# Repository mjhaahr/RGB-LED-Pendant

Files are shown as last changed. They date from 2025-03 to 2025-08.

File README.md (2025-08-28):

# Small RGB LED Pendant with User-Selectable Patterns

Assembled Device

Features:
- 177 Addressable RGB LEDs
    - WS2812B-style (NeoPixel) control
    - Xinglight XL-1010RGBC-WS2812B
- Two-board design for tight packaging
    - Front board contains the LED Matrix
    - Back board holds the Microcontroller, IMU, and Power Regulation
- ESP32-C3 Module for control
    - Allows pattern changing over WiFi/Bluetooth, as well as the buttons on the device
- Onboard IMU to generate reactive patterns
    - Utilizes a Bosch BNO055 for the simplicity of the orientation solution
- USB C Port for Power, Comms, and Programming
    - Connects to the ESP32-C3's onboard USB-CDC/JTAG device

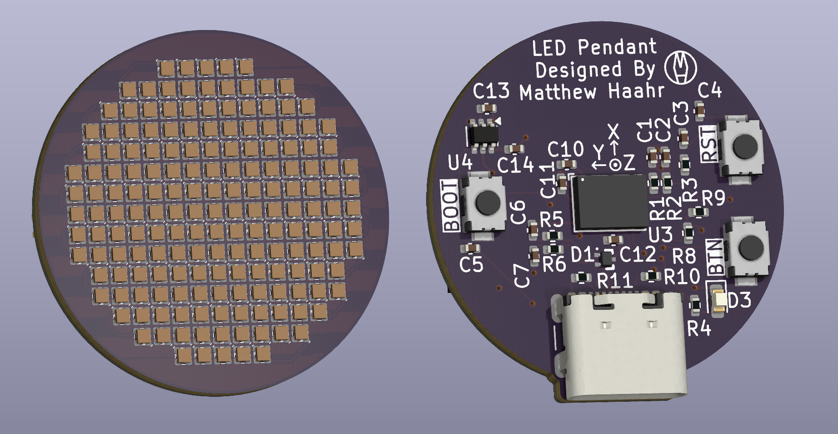
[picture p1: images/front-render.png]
Front Side PCB Render


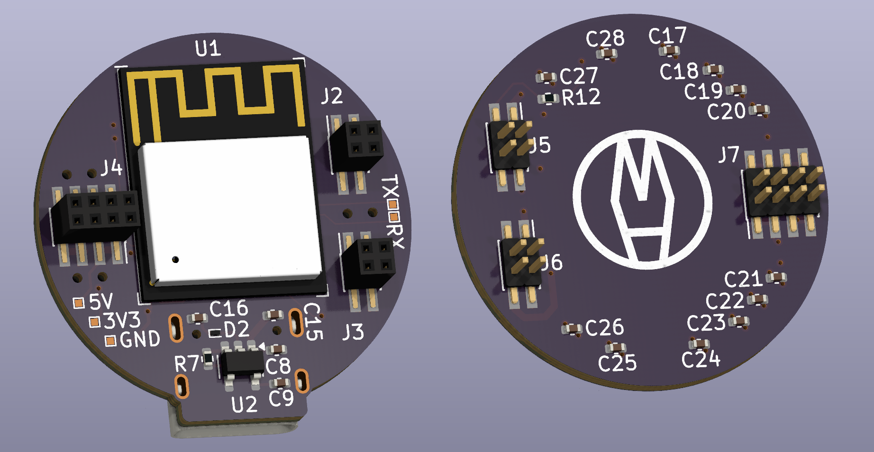
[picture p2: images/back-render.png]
Back Side PCB Render


## Table Of Contents
- [Bill Of Materials](#bill-of-materials)
- [Fabrication and Assembly](#fabrication-and-assembly)
- [Case Design](#case-design)
- [Code](#code)
- [Extra Notes](#extra-notes)

Microcontroller Schematic Page
LED Matrix Schematic Page
LED Support (Capacitors and Connectors) Schematic Page

## Bill of Materials
- 1x Espressif ESP32-C3-MINI-1 - Microcontroller Module w/ WiFi and Bluetooth
    - [Datasheet](https://www.espressif.com/sites/default/files/documentation/esp32-c3-mini-1_datasheet_en.pdf)
    - [LCSC Part Number: C2934569](https://www.lcsc.com/product-detail/WiFi-Modules_Espressif-Systems-ESP32-C3-MINI-1-H4_C2934569.html)
    - Component: U1
- 1x Diodes Incorporated AP2112K-3.3 - Fixed 3V3 Regulator
    - [Datasheet](https://www.diodes.com/assets/Datasheets/AP2112.pdf)
    - [LCSC Part Number: C51118](https://www.lcsc.com/product-detail/Voltage-Regulators-Linear-Low-Drop-Out-LDO-Regulators_Diodes-Incorporated-AP2112K-3-3TRG1_C51118.html)
    - Component: U2
- 1x Bosch Sensortec BNO055 - Absolute Orientation Sensor - 9 Axis IMU and Sensor Fusion Processor
    - [Datasheet](https://www.bosch-sensortec.com/media/boschsensortec/downloads/datasheets/bst-bno055-ds000.pdf)
    - [LCSC Part Number: C93216](https://www.lcsc.com/product-detail/Accelerometers_Bosch-Sensortec-BNO055_C93216.html)
    - Component: U3
- 1x TI SN74LVC1T45DCK - Logic Level Translator
    - [Datasheet](https://www.ti.com/lit/ds/symlink/sn74lvc1t45.pdf)
    - [LCSC Part Number: C9382](https://www.lcsc.com/product-detail/Translators-Level-Shifters_Texas-Instruments-SN74LVC1T45DCKR_C9382.html)
    - Component: U4
- 1x Tech Public TPD2EUSB30 - 2-Channel USB ESD/TVS Diode (Clone of TI part with the same name)
    - [Datasheet](https://www.ti.com/lit/ds/symlink/tpd2eusb30.pdf)
    - [LCSC Part Number: C5182099](https://www.lcsc.com/product-detail/ESD-and-Surge-Protection-TVS-ESD_TECH-PUBLIC-TPD2EUSB30DRTR_C5182099.html)
    - Component: D1
- 1x TI ESD441 - 1-Channel VBUS ESD Diode
    - [Datasheet](https://www.ti.com/lit/ds/symlink/esd441.pdf)
    - [LCSC Part Number: C22427765](https://www.lcsc.com/product-detail/ESD-and-Surge-Protection-TVS-ESD_Texas-Instruments-ESD441DPLR_C22427765.html)
    - Component: D2
- 1x XINGLIGHT XL-1608SYGC-04 - Green LED
    - [Datasheet](https://www.lcsc.com/datasheet/lcsc_datasheet_2410121310_XINGLIGHT-XL-1608SYGC-04_C965806.pdf)
    - [LCSC Part Number: C965806](https://www.lcsc.com/product-detail/LED-Indication-Discrete_XINGLIGHT-XL-1608SYGC-04_C965806.html)
    - Component: D3
- 177x Xinglight XL-1010RGBC-WS2812B - 1mm x 1mm Addressable RGB LED
    - [Datasheet](https://www.lcsc.com/datasheet/lcsc_datasheet_2410121315_XINGLIGHT-XL-1010RGBC-WS2812B_C5349953.pdf)
    - [LCSC Part Number: C5349953](https://www.lcsc.com/product-detail/RGB-LEDs-Built-in-IC_XINGLIGHT-XL-1010RGBC-WS2812B_C5349953.html)
    - Component: D4-D180
- 3x Bossie BX-TS-26-342TP - SMD Tactile Push Buttons:
    - [Datasheet](https://www.lcsc.com/datasheet/lcsc_datasheet_2410121625_Bossie-BX-TS-26-342TP_C18078117.pdf)
    - [LCSC Part Number: C18078117](https://www.lcsc.com/product-detail/Tactile-Switches_Bossie-BX-TS-26-342TP_C18078117.html)
    - Component: SW1-SW3
- 1x G-Switch GT-USB-9010AB - USB 2.0 USB-C Connector (GCT-USB4105-GF Clone)
    - [Datasheet](https://www.lcsc.com/datasheet/lcsc_datasheet_2411221125_G-Switch-GT-USB-9010AB_C2988366.pdf)
    - [LCSC Part Number: C2988366](https://www.lcsc.com/product-detail/USB-Connectors_G-Switch-GT-USB-9010AB_C2988366.html)
    - Component: J1
- Headers (Used as Interboard Connectors)
    - 2x 2x2 Pin Socket - 1.27mm Pitch - Vertical SMD
        - Component: J2, J3
        - [LCSC Part Number: C5160799](https://www.lcsc.com/product-detail/Female-Headers_DEALON-DW127S-22-04-43_C5160799.html)
    - 1x 2x4 Pin Socket - 1.27mm Pitch - Vertical SMD
        - Component: J4
        - [LCSC Part Number: C5160801](https://www.lcsc.com/product-detail/Female-Headers_DEALON-DW127S-22-08-43_C5160801.html)
    - 2x 2x2 Pin Header - 1.27mm Pitch - Vertical SMD
        - Component: J5, J6
        - [LCSC Part Number: C5160758](https://www.lcsc.com/product-detail/Pin-Headers_DEALON-DZ127S-22-04-55_C5160758.html)
    - 1x 2x4 Pin Header - 1.27mm Pitch - Vertical SMD
        - Component: J7
        - [LCSC Part Number: C5160760](https://www.lcsc.com/product-detail/Pin-Headers_DEALON-DZ127S-22-08-55_C5160760.html)
- Capacitors
    - *All Packages are 0402 unless otherwise noted*
    - 10µF
        - Component: C1, C8, C9, C16
        - [LCSC Part Number: C7472949](https://www.lcsc.com/product-detail/Multilayer-Ceramic-Capacitors-MLCC-SMD-SMT_Chinocera-HGC0402R5106M100NTEJ_C7472949.html)
    - 100nF
        - Component: C2, C4, C5, C10, C13, C14, C17-C28
        - [LCSC Part Number: C1525](https://www.lcsc.com/product-detail/Multilayer-Ceramic-Capacitors-MLCC-SMD-SMT_Samsung-Electro-Mechanics-CL05B104KO5NNNC_C1525.html)
    - 1µF
        - Component: C3, C12, C15
        - [LCSC Part Number: C14445](https://www.lcsc.com/product-detail/Multilayer-Ceramic-Capacitors-MLCC-SMD-SMT_Samsung-Electro-Mechanics-CL05A105KP5NNNC_C14445.html)
    - 22pF
        - Component: C6, C7
        - [LCSC Part Number: C106203](https://www.lcsc.com/product-detail/Multilayer-Ceramic-Capacitors-MLCC-SMD-SMT_YAGEO-CC0402JRNPO9BN220_C106203.html)
    - 120nF
        - Component: C11
        - [LCSC Part Number: C7393864](https://www.lcsc.com/product-detail/Multilayer-Ceramic-Capacitors-MLCC-SMD-SMT_CCTC-TCC0402X7R124K160AT_C7393864.html)
- Resistors:
    - *All Packages are 0402 unless otherwise noted*
    - 3.3kΩ
        - Component: R1, R2
        - [LCSC Part Number: C25890](https://www.lcsc.com/product-detail/Chip-Resistor-Surface-Mount_UNI-ROYAL-Uniroyal-Elec-0402WGF3301TCE_C25890.html)
    - 10kΩ
        - Component: R3, R8, R9, R12
        - [LCSC Part Number: C25744](https://www.lcsc.com/product-detail/Chip-Resistor-Surface-Mount_UNI-ROYAL-Uniroyal-Elec-0402WGF1002TCE_C25744.html)
    - 1.3kΩ
        - Component: R4
        - [LCSC Part Number: C25866](https://www.lcsc.com/product-detail/Chip-Resistor-Surface-Mount_UNI-ROYAL-Uniroyal-Elec-0402WGF1301TCE_C25866.html)
    - 0Ω
        - Component: R5, R6
        - [LCSC Part Number: C17168](https://www.lcsc.com/product-detail/Chip-Resistor-Surface-Mount_UNI-ROYAL-Uniroyal-Elec-0402WGF0000TCE_C17168.html)
    - 100kΩ
        - Component: R7
        - [LCSC Part Number: C25741](https://www.lcsc.com/product-detail/Chip-Resistor-Surface-Mount_UNI-ROYAL-Uniroyal-Elec-0402WGF1003TCE_C25741.html)
    - 5.1kΩ
        - Component: R10, R11
        - [LCSC Part Number: C25905](https://www.lcsc.com/product-detail/Chip-Resistor-Surface-Mount_UNI-ROYAL-Uniroyal-Elec-0402WGF5101TCE_C25905.html)
    - 470Ω
        - Component: R13
        - [LCSC Part Number: C25117](https://www.lcsc.com/product-detail/Chip-Resistor-Surface-Mount_UNI-ROYAL-Uniroyal-Elec-0402WGF4700TCE_C25117.html)

## Fabrication and Assembly
- The boards were fabricated and assembled by JLCPCB
- The boards were combined into one frame to reduce the cost of having to make and assemble two designs in one order
- The frame was enlarged to fit the minimum board size for JLCPCB's PCBA service, as well as providing the necessary fiducials and edge rails for assembly

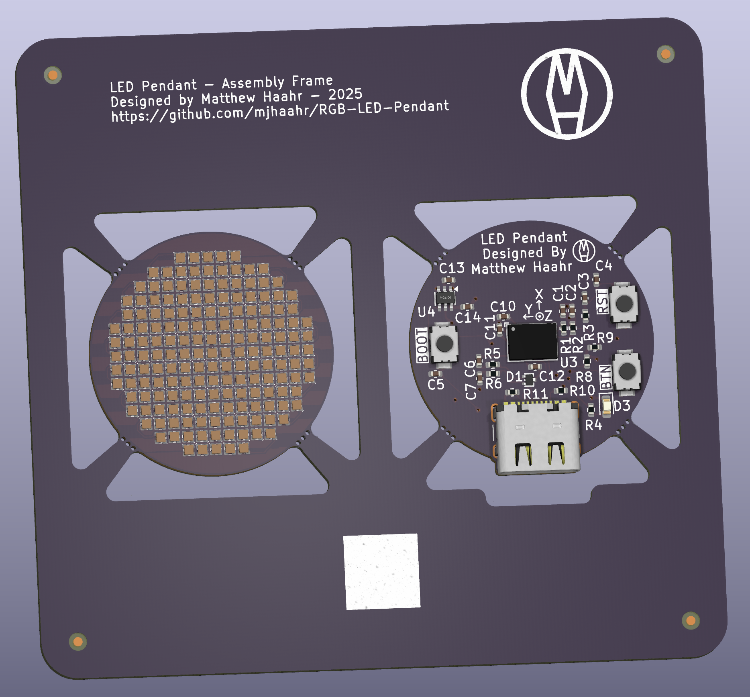
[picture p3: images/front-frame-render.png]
Front Side Assembly Frame Render


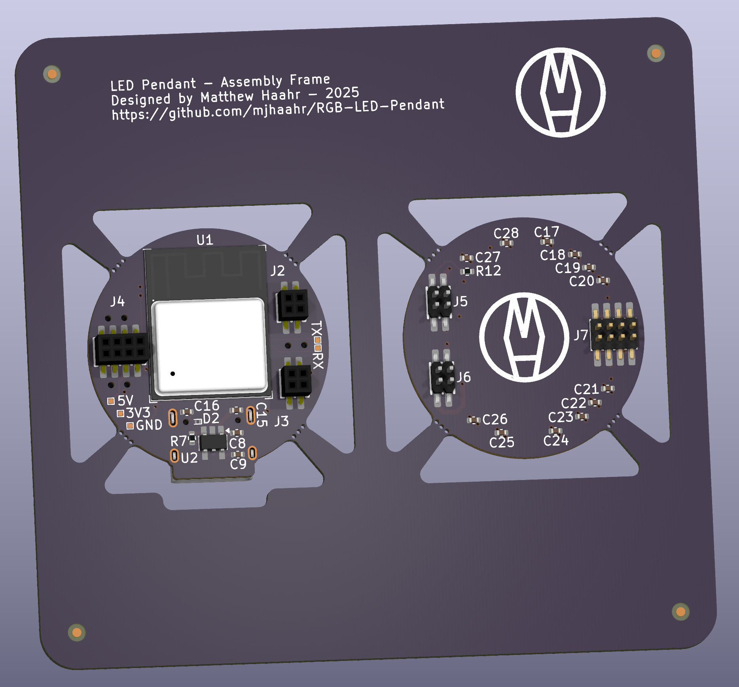
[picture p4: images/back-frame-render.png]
Back Side Assembly Frame Render


## Case Design
<!--- *TODO: Make Alternate with no Loop* --->
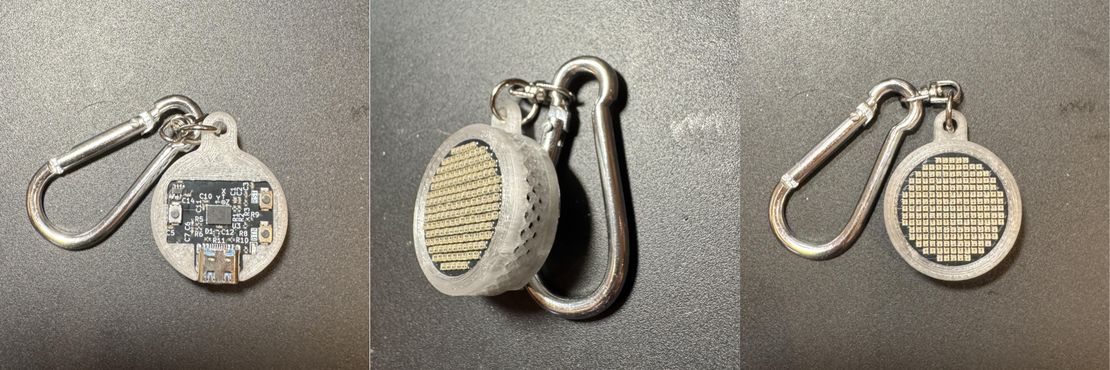
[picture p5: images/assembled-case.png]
Assembled Case


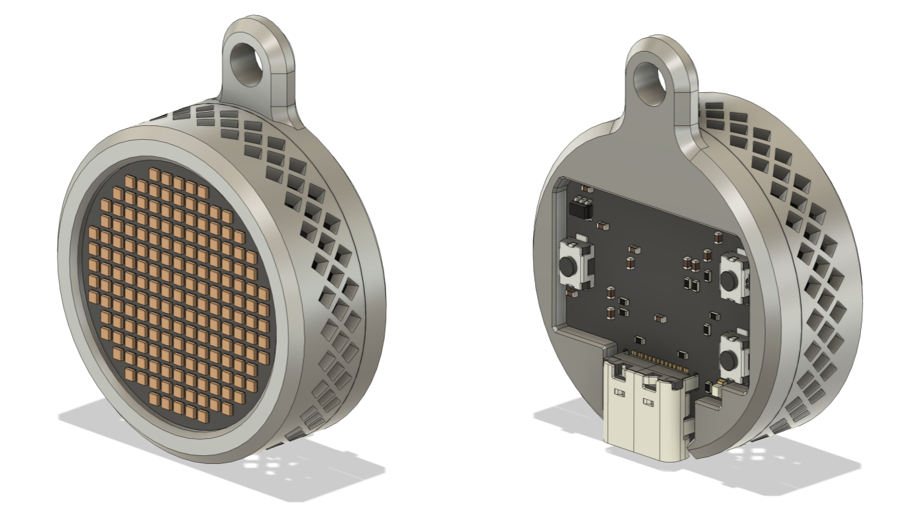
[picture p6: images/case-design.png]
Case Design


- 3D Printed Case with Keyring Loop
- Due to the small size, the two halves must be glued together, so ensure the whole pendant works before gluing together
- Included are the [CAD Files](case/Models) and [STLs](case/3D_Prints)

## Code
- Open the [Arduino Project](code/Small_Pendant) (Small_Pendant.ino and the rest of the directory)
- Ensure the ESP32 Arduino Core is installed and select the ESP32C3 Dev Module
- Plug in the pendant and click upload

## Extra Notes
- The [Only Pendant](https://github.com/mjhaahr/RGB-LED-Pendant/tree/Only_Pendant) branch features a much-simplified design, with only the LED Matrix and no control board; it functions the same as a normal NeoPixel matrix.
- A future version may replace the BNO055 with a more up-to-date IMU (and one that is a still active product) and move the orientation calculation onto the main MCU
- A future design may include an onboard battery and charger (would likely require enlarging the board or adding thickness to the design)
- During standup of V1 Hardware, it was found that an MCU strapping pin was forgotten (10kΩ pull-up on GPIO8)
    - To get the first run boards working, an 8.06kΩ 0603 pull-up resistor was added across pins 4 (GPIO8/`LED_Data`) and 6 (3V3) of U4
    - Fixed for future revision with a 10kΩ 0402 pull-up resistor placed closer to the MCU Module (U1)

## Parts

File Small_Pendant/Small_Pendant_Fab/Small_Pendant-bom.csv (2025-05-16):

Designator | Value | Qty | Footprint | LCSC Part
C1,C8,C9,C16 | 10uF | 4 | Capacitor_SMD:C_0402_1005Metric | C7472949
C2,C4,C5,C10,C13,C14,C17,C18,C19,C20,C21,C22,C23,C24,C25,C26,C27,C28 | 100nF | 18 | Capacitor_SMD:C_0402_1005Metric | C1525
C3,C12,C15 | 1uF | 3 | Capacitor_SMD:C_0402_1005Metric | C14445
C6,C7 | 22pF | 2 | Capacitor_SMD:C_0402_1005Metric | C106203
C11 | 120nF | 1 | Capacitor_SMD:C_0402_1005Metric | C7393864
D1 | TPD2EUSB30 | 1 | TPD2EUSB30DRTR:DRT0003A | C5182099
D2 | ESD441DPLR | 1 | EasyEDA2KiCad:X2SON-2_L0.6-W0.3-P0.35_ESD441DPLR | C22427765
D3 | GREEN | 1 | LED_SMD:LED_0603_1608Metric | C965806
D4,D5,D6,D7,D8,D9,D10,D11,D12,D13,D14,D15,D16,D17,D18,D19,D20,D21,D22,D23,D24,D25,D26,D27,D28,D29,D30,D31,D32,D33,D34,D35,D36,D37,D38,D39,D40,D41,D42,D43,D44,D45,D46,D47,D48,D49,D50,D51,D52,D53,D54,D55,D56,D57,D58,D59,D60,D61,D62,D63,D64,D65,D66,D67,D68,D69,D70,D71,D72,D73,D74,D75,D76,D77,D78,D79,D80,D81,D82,D83,D84,D85,D86,D87,D88,D89,D90,D91,D92,D93,D94,D95,D96,D97,D98,D99,D100,D101,D102,D103,D104,D105,D106,D107,D108,D109,D110,D111,D112,D113,D114,D115,D116,D117,D118,D119,D120,D121,D122,D123,D124,D125,D126,D127,D128,D129,D130,D131,D132,D133,D134,D135,D136,D137,D138,D139,D140,D141,D142,D143,D144,D145,D146,D147,D148,D149,D150,D151,D152,D153,D154,D155,D156,D157,D158,D159,D160,D161,D162,D163,D164,D165,D166,D167,D168,D169,D170,D171,D172,D173,D174,D175,D176,D177,D178,D179,D180 | XL-1010RGBC-WS2812B | 177 | LED_SMD:XINGLIGHT-XL-1010RGBC | C5349953
J1 | USB_C_Receptacle_USB2.0_16P | 1 | Connector_USB:USB_C_Receptacle_GCT_USB4105-xx-A_16P_TopMnt_Horizontal | C2988366
J2,J3 | Interboard-F1 | 2 | Connector_PinSocket_1.27mm:PinSocket_2x02_P1.27mm_Vertical_SMD | C5160799
J4 | Interboard-F2 | 1 | Connector_PinSocket_1.27mm:PinSocket_2x04_P1.27mm_Vertical_SMD | C5160801
J5,J6 | Interboard-M1 | 2 | Connector_PinHeader_1.27mm:PinHeader_2x02_P1.27mm_Vertical_SMD | C5160758
J7 | Interboard-M2 | 1 | Connector_PinHeader_1.27mm:PinHeader_2x04_P1.27mm_Vertical_SMD | C5160760
R1,R2 | 3.3k | 2 | Resistor_SMD:R_0402_1005Metric | C25890
R3,R8,R9,R13 | 10k | 3 | Resistor_SMD:R_0402_1005Metric | C25744
R4 | 1k3 | 1 | Resistor_SMD:R_0402_1005Metric | C25866
R5,R6 | 0 | 2 | Resistor_SMD:R_0402_1005Metric | C17168
R7 | 100k | 1 | Resistor_SMD:R_0402_1005Metric | C25741
R10,R11 | 5k1 | 2 | Resistor_SMD:R_0402_1005Metric | C25905
R13 | 470 | 1 | Resistor_SMD:R_0402_1005Metric | C25117
SW1,SW2,SW3 | SW_Push | 3 | EasyEDA2KiCad:KEY-SMD_L3.9-W3.0-LS5.0-EH | C18078117
U1 | ESP32-C3-MINI-1 | 1 | MCU_Espressif_Official:ESP32-C3-MINI-1 | C2934569
U2 | AP2112K-3.3 | 1 | Package_TO_SOT_SMD:SOT-23-5 | C51118
U3 | BNO055 | 1 | BNO055:LGA28R50P4X10_380X520X100 | C93216
U4 | SN74LVC1T45DCK | 1 | Package_TO_SOT_SMD:SOT-363_SC-70-6 | C9382

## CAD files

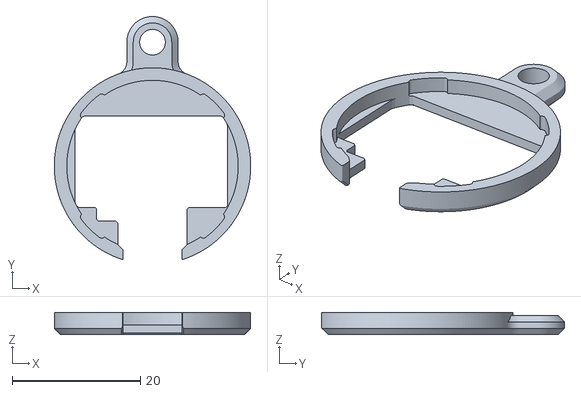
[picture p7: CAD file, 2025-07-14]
case/3D_Prints/MCU Side.stl
30.6 x 37.9 x 3.50

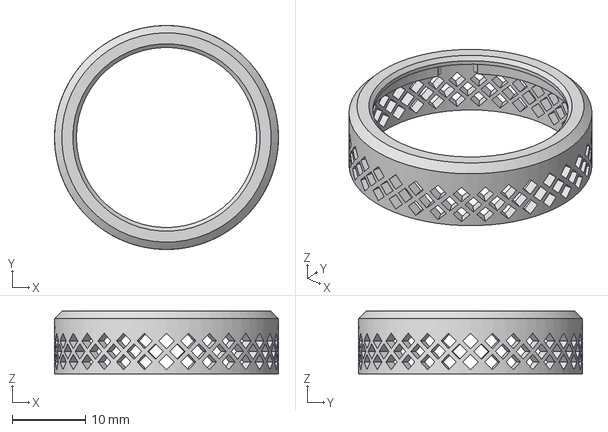
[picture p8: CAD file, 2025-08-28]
case/Models/LED Side Case.step
30.6 x 30.6 x 8.55 mm

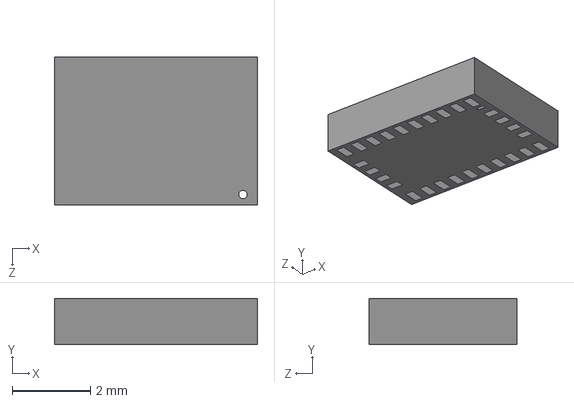
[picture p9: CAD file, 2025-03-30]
Small_Pendant/parts/BNO055/BNO055.step
5.20 x 1.18 x 3.80 mm

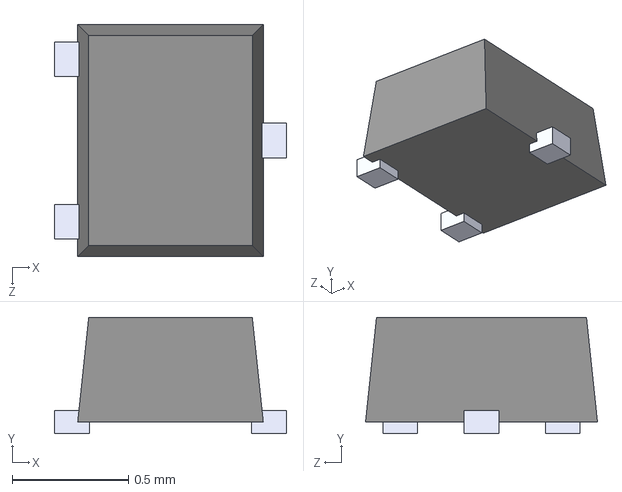
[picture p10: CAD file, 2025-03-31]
Small_Pendant/parts/TPD2EUSB30DRTR/TPD2EUSB30DRTR.step
1.00 x 0.5 x 1.00 mm

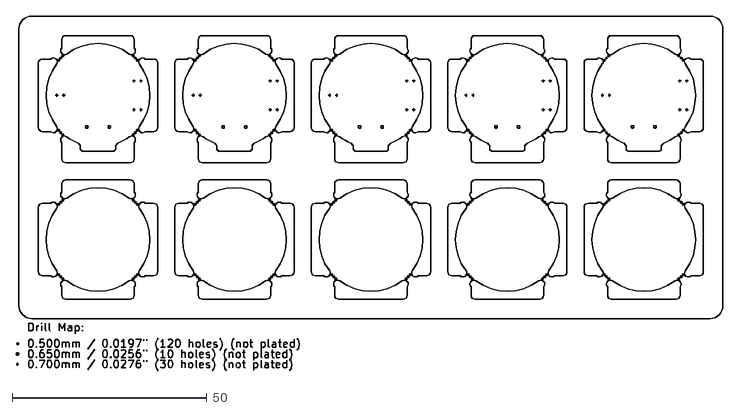
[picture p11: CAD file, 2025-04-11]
Small_Pendant/production/Small_Pendant_Fab/Small_Pendant_Gerbers/Small_Pendant-NPTH-drl_map.dxf
181.3 x 91.0

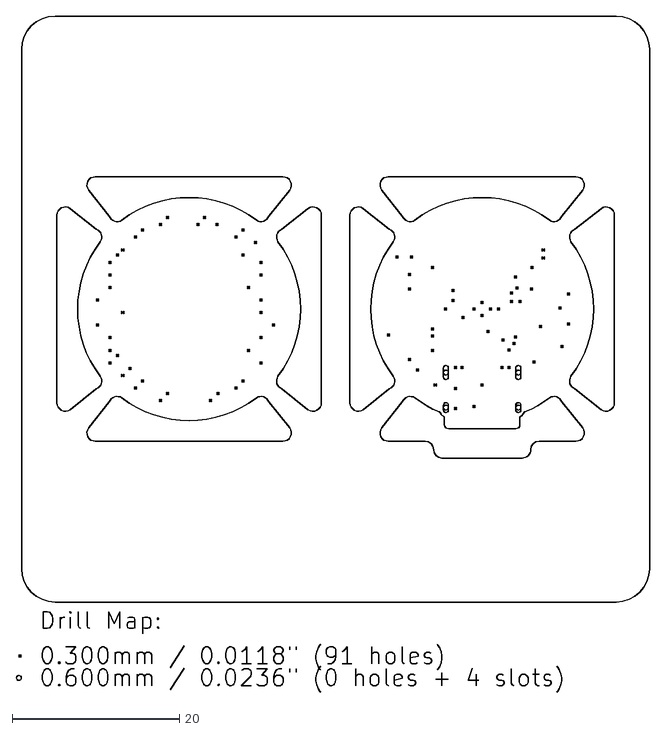
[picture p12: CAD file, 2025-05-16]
Small_Pendant/Small_Pendant_Fab/Small_Pendant_Gerbers/Small_Pendant-PTH-drl_map.dxf
75.6 x 80.7

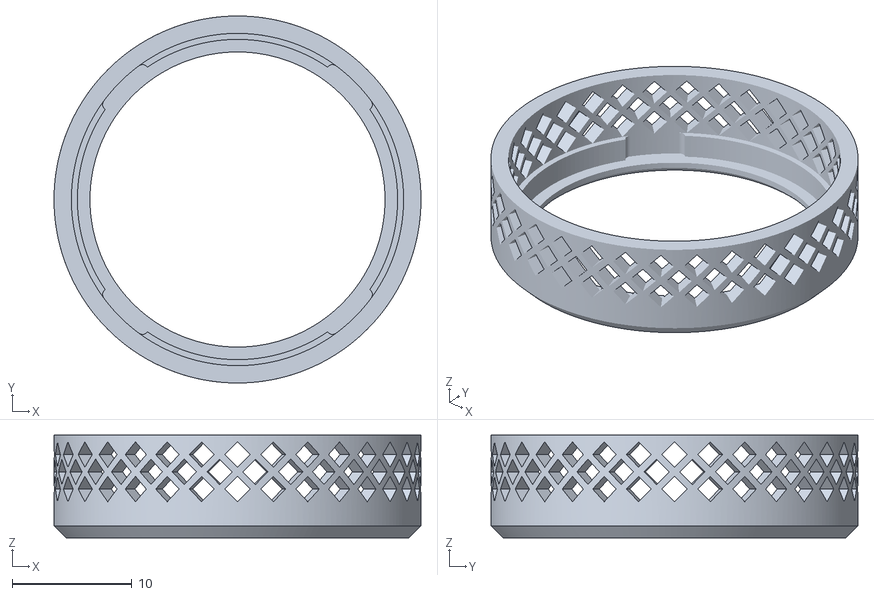
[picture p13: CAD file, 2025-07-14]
case/3D_Prints/LED Side.stl
30.6 x 30.6 x 8.55

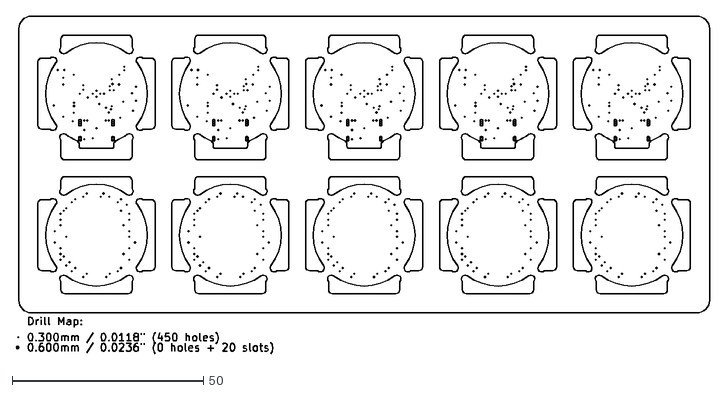
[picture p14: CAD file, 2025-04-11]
Small_Pendant/production/Small_Pendant_Fab/Small_Pendant_Gerbers/Small_Pendant-PTH-drl_map.dxf
181.2 x 88.3

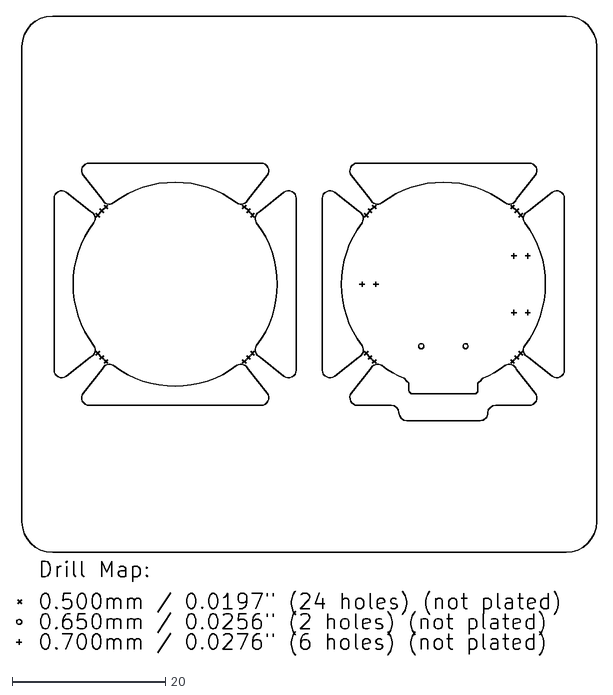
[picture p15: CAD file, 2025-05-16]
Small_Pendant/Small_Pendant_Fab/Small_Pendant_Gerbers/Small_Pendant-NPTH-drl_map.dxf
75.7 x 83.4

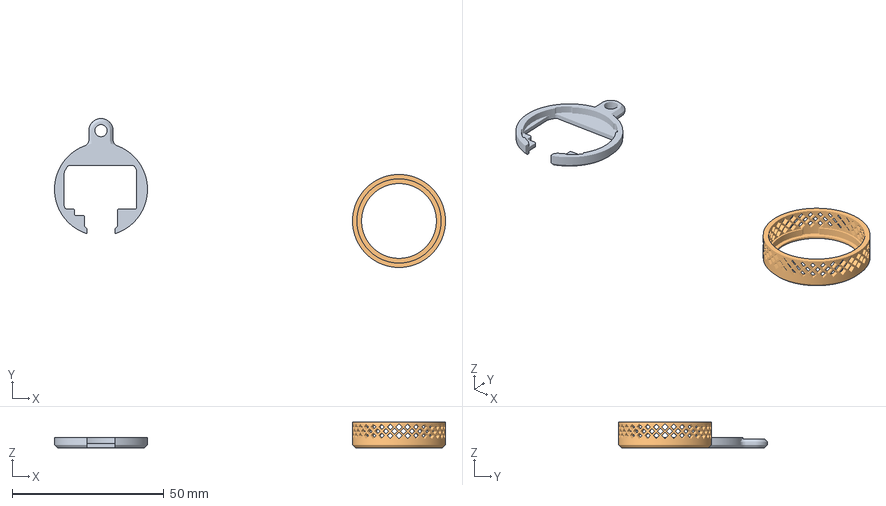
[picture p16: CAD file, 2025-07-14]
case/3D_Prints/Small Pendant Case.3mf
128.7 x 49.0 x 8.55 mm
MCU Side
LED Side

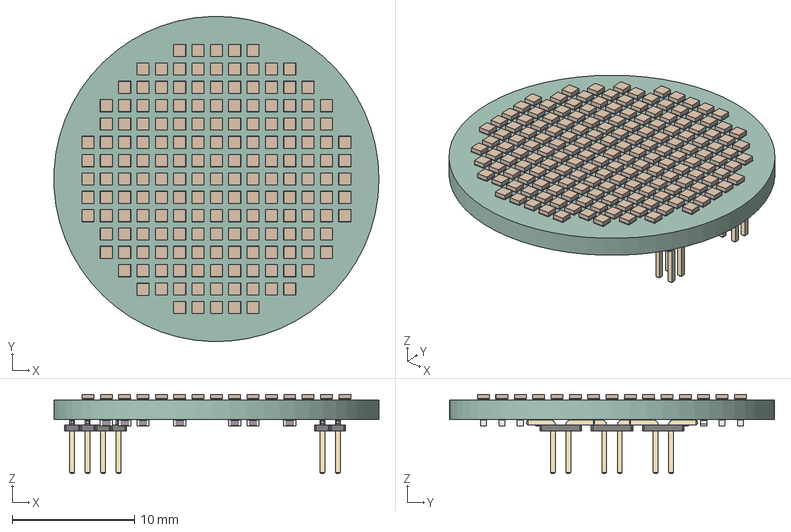
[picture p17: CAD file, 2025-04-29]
case/Models/led_board.step
26.6 x 26.6 x 6.50 mm
(Unsaved) x 177
C_0402_1005Metric x 12
PinHeader_2x02_P127mm_Vertical_SMD x 2
PinHeader_2x04_P127mm_Vertical_SMD
R_0402_1005Metric
led_board_PCB

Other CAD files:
case/Models/MCU Side Case.step

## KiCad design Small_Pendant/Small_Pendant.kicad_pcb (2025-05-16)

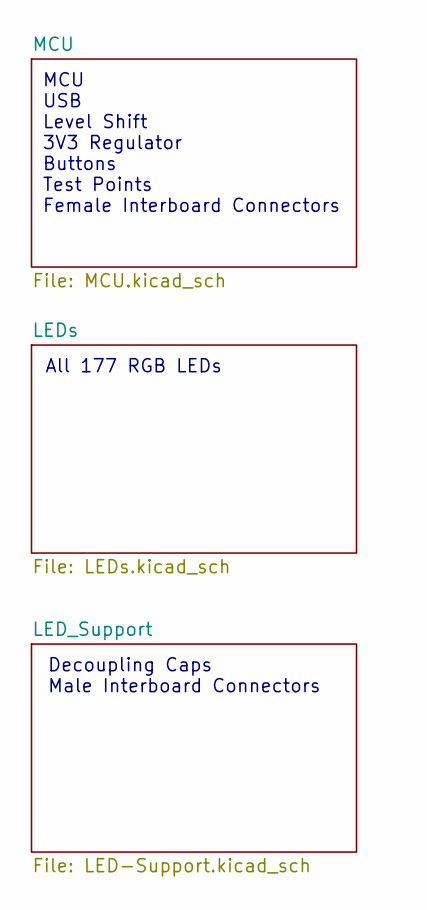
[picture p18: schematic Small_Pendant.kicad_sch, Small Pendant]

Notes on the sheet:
All 177 RGB LEDs
Decoupling Caps Male Interboard Connectors
MCU USB Level Shift 3V3 Regulator Buttons Test Points Female Interboard Connectors

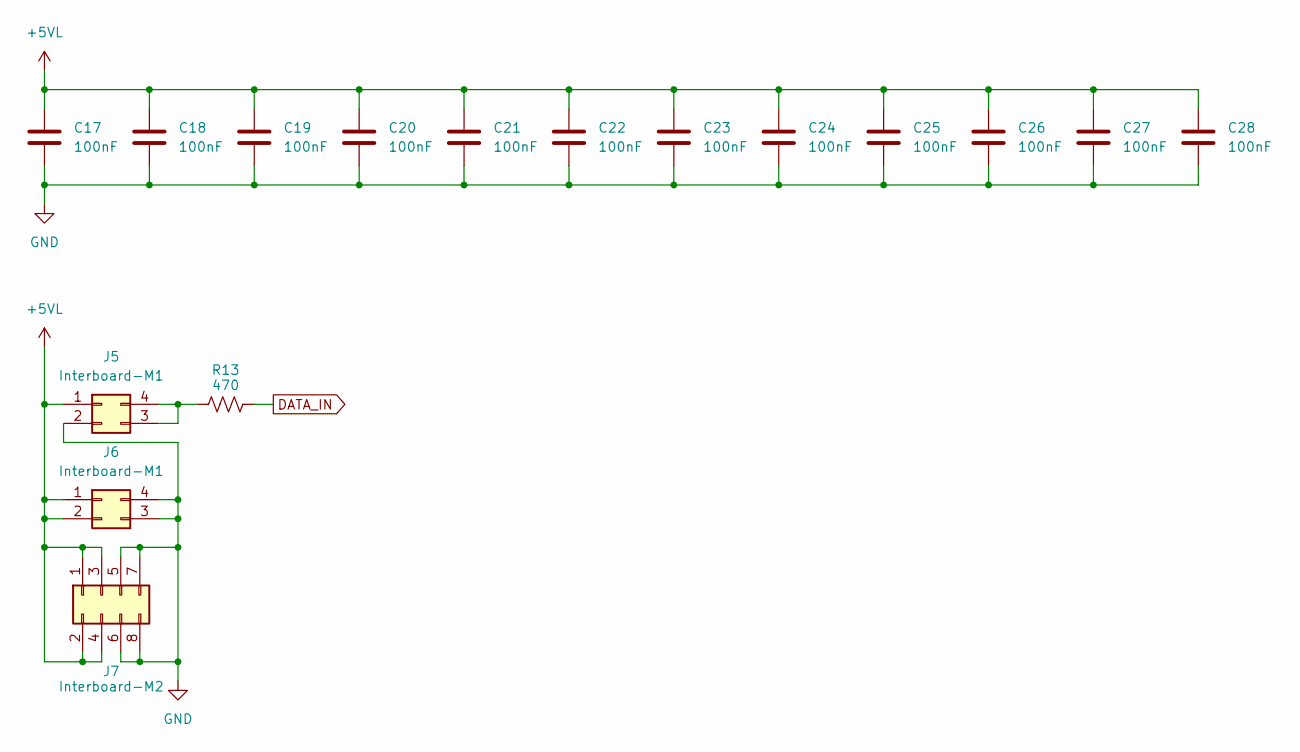
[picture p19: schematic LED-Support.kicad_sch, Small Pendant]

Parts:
C17, C18, C19, C20, C21, C22, C23, C24, C25, C26, C27, C28: 100nF; C_0402_1005Metric; LCSC Part C1525
J5, J6: Interboard-M1; HDR-SMD_4P-P1.27-V-M-R2-C2-S1.27-LS5.5; LCSC Part C5160758
J7: Interboard-M2; HDR-SMD_8P-P1.27-V-M-R2-C4-W5.5; LCSC Part C5160760
R13: 470; R_0402_1005Metric; LCSC Part C25117

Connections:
+5VL: C17.1, C18.1, C19.1, C20.1, C21.1, C22.1, C23.1, C24.1, C25.1, C26.1, C27.1, C28.1, J5.1, J6.1, J6.2, J7.1, J7.2, J7.3, J7.4; also elsewhere on the board
DATA_IN: R13.2; also elsewhere on the board
GND: C17.2, C18.2, C19.2, C20.2, C21.2, C22.2, C23.2, C24.2, C25.2, C26.2, C27.2, C28.2, J5.2, J6.3, J6.4, J7.5, J7.6, J7.7, J7.8; also elsewhere on the board
unnamed: J5.3, J5.4, R13.1

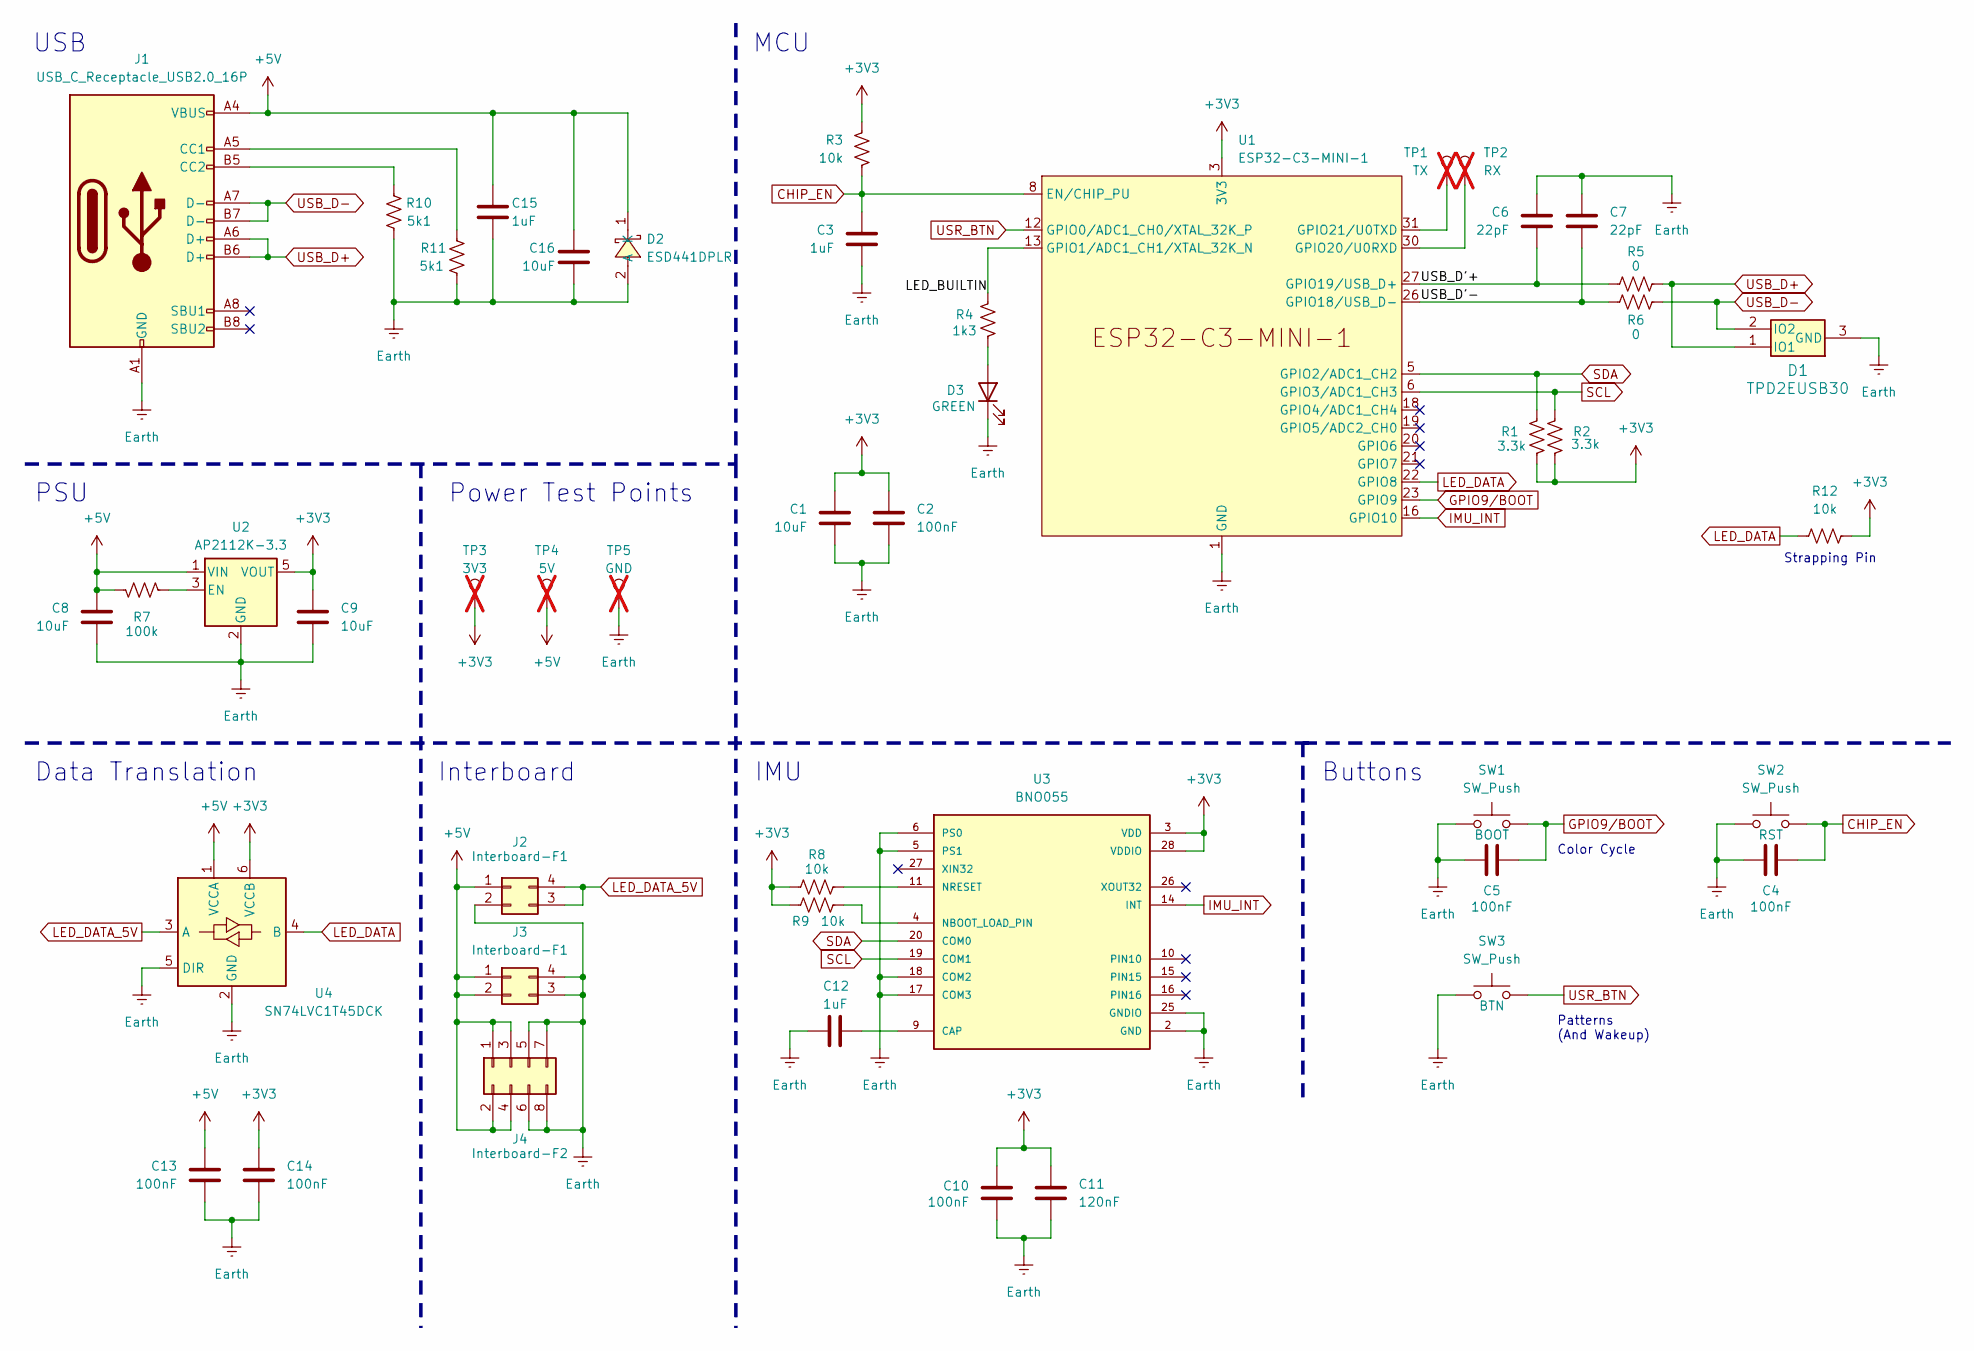
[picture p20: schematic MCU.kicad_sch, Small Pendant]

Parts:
C1, C8, C9, C16: 10uF; C_0402_1005Metric; LCSC Part C7472949
C2, C4, C5, C10, C13, C14: 100nF; C_0402_1005Metric; LCSC Part C1525
C3, C12, C15: 1uF; C_0402_1005Metric; LCSC Part C14445
C6, C7: 22pF; C_0402_1005Metric; LCSC Part C106203
C11: 120nF; C_0402_1005Metric; LCSC Part C7393864
D1: TPD2EUSB30; SOT-723_L1.2-W0.8-P0.80-LS1.2-BR; LCSC Part C5182099
D2: ESD441DPLR; X2SON-2_L0.6-W0.3-P0.35_ESD441DPLR; LCSC Part C22427765
D3: GREEN; LED_0603_1608Metric; LCSC Part C965806
J1: USB_C_Receptacle_USB2.0_16P; USB-C-SMD_G-SWITCH_GT-USB-9010AB; LCSC Part C2988366
J2, J3: Interboard-F1; HDR-SMD_4P-P1.27-V-F-R2-C2-LS4.8; LCSC Part C5160799
J4: Interboard-F2; HDR-SMD_8P-P1.27-V-F-R2-C4-LS4.8; LCSC Part C5160801
R1, R2: 3.3k; R_0402_1005Metric; LCSC Part C25890
R3, R8, R9: 10k; R_0402_1005Metric; LCSC Part C25744
R4: 1k3; R_0402_1005Metric; LCSC Part C25866
R5, R6: 0; R_0402_1005Metric; LCSC Part C17168
R7: 100k; R_0402_1005Metric; LCSC Part C25741
R10, R11: 5k1; R_0402_1005Metric; LCSC Part C25905
R12: 10k; R_0402_1005Metric
SW1, SW2, SW3: SW_Push; KEY-SMD_L3.9-W3.0-LS5.0-EH; LCSC Part C18078117
TP1: TX; TestPoint_Pad_0.5x0.5mm; not fitted
TP2: RX; TestPoint_Pad_0.5x0.5mm; not fitted
TP3: 3V3; TestPoint_Pad_0.5x0.5mm; not fitted
TP4: 5V; TestPoint_Pad_0.5x0.5mm; not fitted
TP5: GND; TestPoint_Pad_0.5x0.5mm; not fitted
U1: ESP32-C3-MINI-1; WIFIM-SMD_ESP32-C3-MINI-1; LCSC Part C2934569
U2: AP2112K-3.3; SOT-25-5_L2.9-W1.6-P0.95-LS2.8-BL; LCSC Part C22427765
U3: BNO055; LGA-28_L5.2-W3.8-P0.50-BL; LCSC Part C93216
U4: SN74LVC1T45DCK; SC-70-6_L2.2-W1.3-P0.65-LS2.2-BR; LCSC Part C9382

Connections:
+3V3: C1.1, C2.1, C9.1, C10.2, C11.1, C14.1, R1.2, R2.2, R3.1, R8.1, R9.1, R12.2, TP3.1, U1.3 (3V3), U2.5 (VOUT), U3.3 (VDD), U3.28 (VDDIO), U4.6 (VCCB)
+5V: C8.1, C13.1, C15.1, C16.1, D2.1 (K), J1.A4 (VBUS), J1.A9 (VBUS), J1.B4 (VBUS), J1.B9 (VBUS), J2.1, J3.1, J3.2, J4.1, J4.2, J4.3, J4.4, R7.1, TP4.1, U2.1 (VIN), U4.1 (VCCA)
/MCU/LED_BUILTIN: R4.2, U1.13 (GPIO1/ADC1_CH1/XTAL_32K_N)
/MCU/USB_D'+: C6.2, R5.1, U1.27 (GPIO19/USB_D+)
/MCU/USB_D'-: C7.2, R6.1, U1.26 (GPIO18/USB_D-)
CHIP_EN: C3.1, C4.1, R3.2, SW2.2, U1.8 (EN/CHIP_PU)
Earth: C1.2, C2.2, C3.2, C4.2, C5.2, C6.1, C7.1, C8.2, C9.2, C10.1, C11.2, C12.2, C13.2, C14.2, C15.2, C16.2, D1.3 (GND), D2.2 (A), D3.1 (K), J1.A1 (GND), J1.A12 (GND), J1.B1 (GND), J1.B12 (GND), J2.2, J3.3, J3.4, J4.5, J4.6, J4.7, J4.8, R10.2, R11.2, SW1.1, SW2.1, SW3.1, TP5.1, U1.1 (GND), U1.2 (GND), U1.11 (GND), U1.14 (GND), U1.36 (GND), U1.37 (GND), U1.38 (GND), U1.39 (GND), U1.40 (GND), U1.41 (GND), U1.42 (GND), U1.43 (GND), U1.44 (GND), U1.45 (GND), U1.46 (GND), U1.47 (GND), U1.48 (GND), U1.49 (GND), U1.50 (GND), U1.51 (GND), U1.52 (GND), U1.53 (GND), U2.2 (GND), U3.2 (GND), U3.5 (PS1), U3.6 (PS0), U3.17 (COM3), U3.18 (COM2), U3.25 (GNDIO), U4.2 (GND), U4.5 (DIR)
GPIO9/BOOT: C5.1, SW1.2, U1.23 (GPIO9)
IMU_INT: U1.16 (GPIO10), U3.14 (INT)
LED_DATA: R12.1, U1.22 (GPIO8), U4.4 (B)
LED_DATA_5V: J2.3, J2.4, U4.3 (A)
unnamed: D3.2 (A), R4.1
unnamed: J1.A5 (CC1), R11.1
unnamed: J1.B5 (CC2), R10.1
unnamed: TP2.1, U1.30 (GPIO20/U0RXD)
unnamed: TP1.1, U1.31 (GPIO21/U0TXD)
unnamed: R7.2, U2.3 (EN)
unnamed: C12.1, U3.9 (CAP)
unnamed: R9.2, U3.4 (NBOOT_LOAD_PIN)
unnamed: R8.2, U3.11 (NRESET)
SCL: R2.1, U1.6 (GPIO3/ADC1_CH3), U3.19 (COM1)
SDA: R1.1, U1.5 (GPIO2/ADC1_CH2), U3.20 (COM0)
USB_D+: D1.1 (IO1), J1.A6 (D+), J1.B6 (D+), R5.2
USB_D-: D1.2 (IO2), J1.A7 (D-), J1.B7 (D-), R6.2
USR_BTN: SW3.2, U1.12 (GPIO0/ADC1_CH0/XTAL_32K_P)

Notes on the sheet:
USB
Data Translation
Buttons
Patterns (And Wakeup)
PSU
Power Test Points
Strapping Pin
Interboard
MCU
Color Cycle
IMU

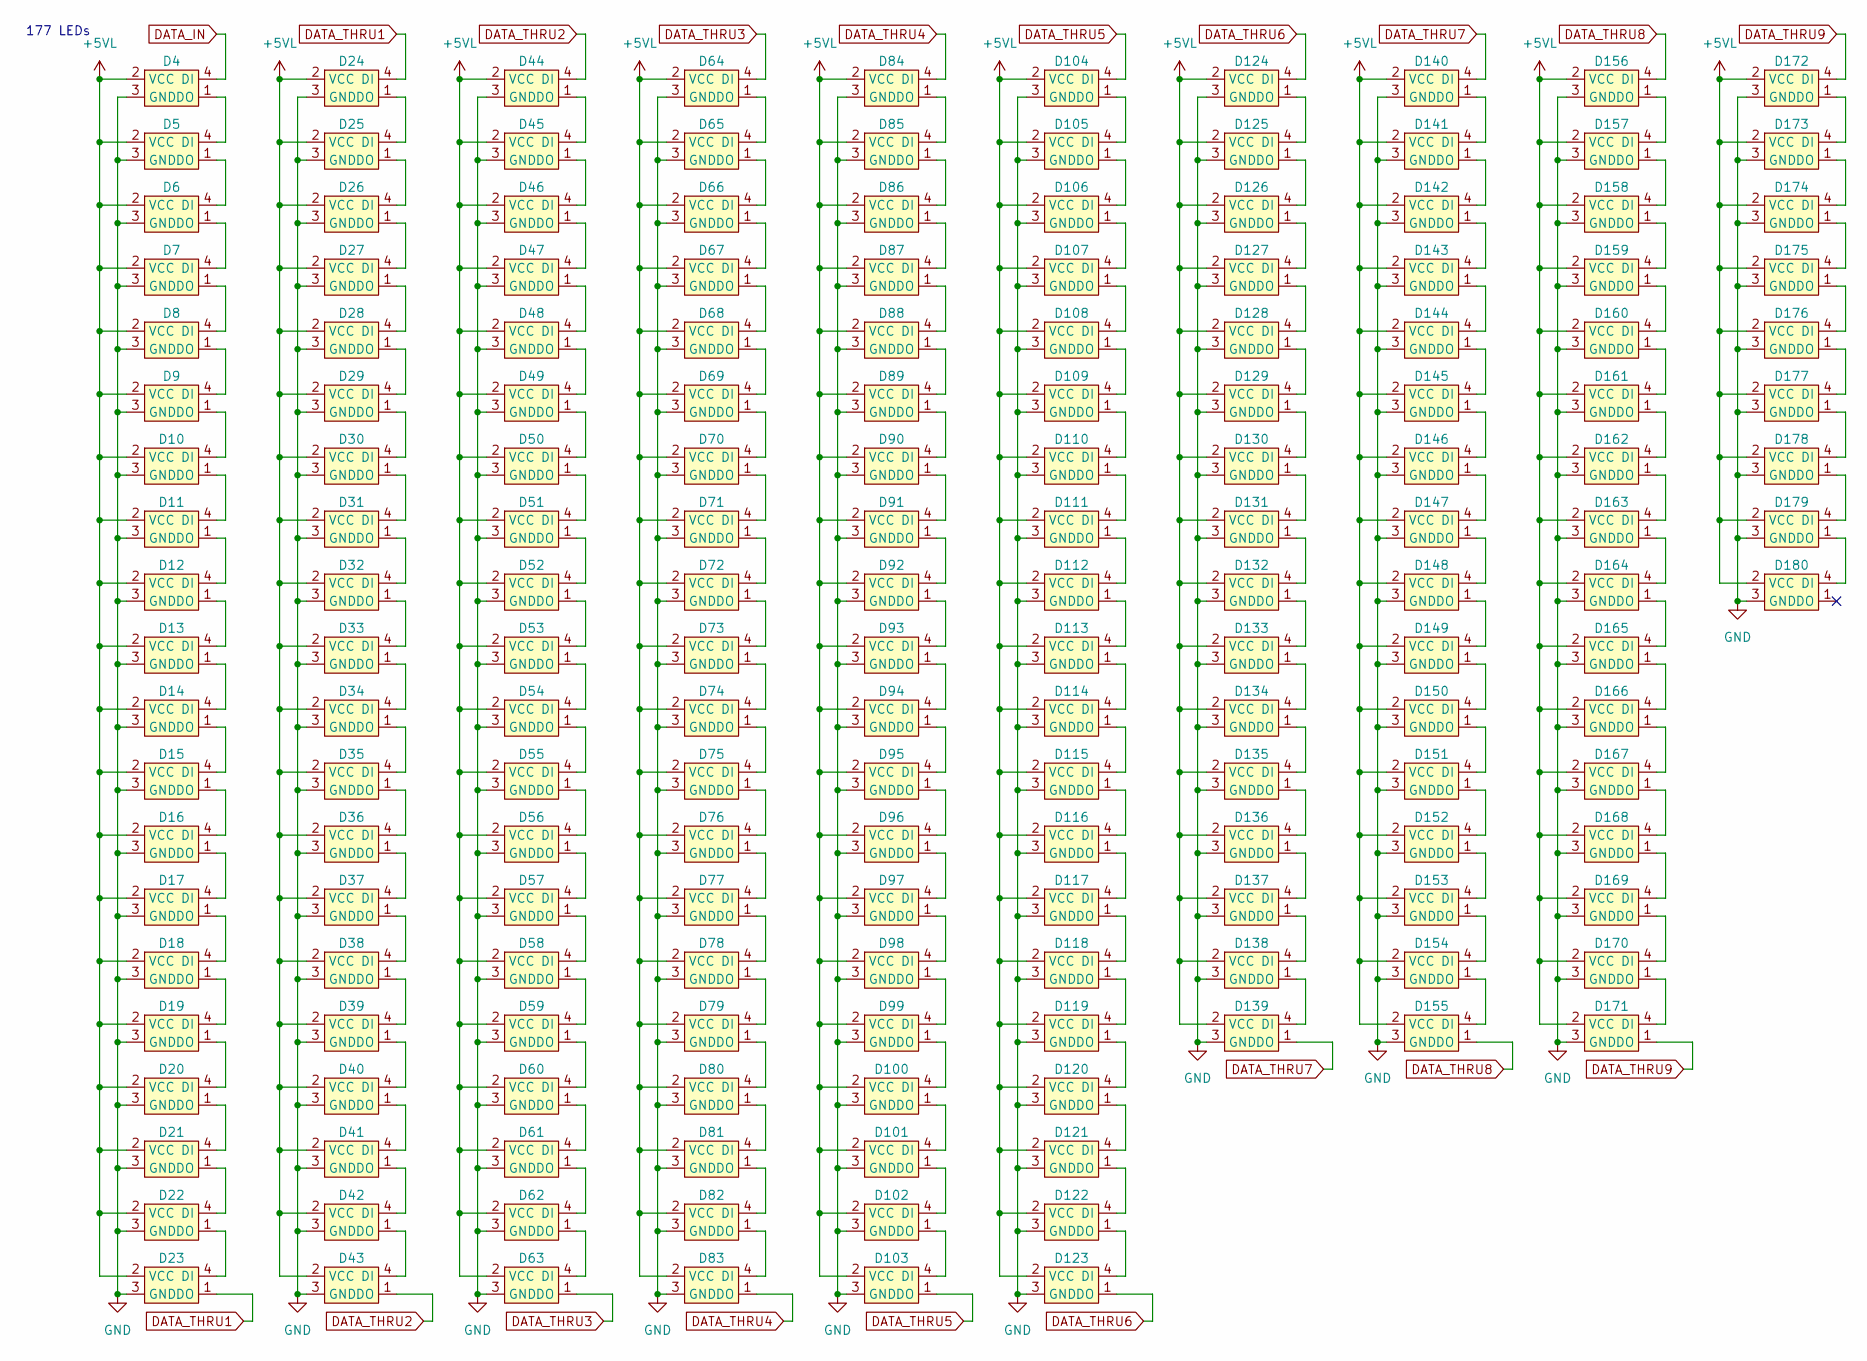
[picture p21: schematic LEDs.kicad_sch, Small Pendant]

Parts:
D4, D5, D6, D7, D8, D9, D10, D11, D12, D13, D14, D15, D16, D17, D18, D19, D20, D21, D22, D23, D24, D25, D26, D27, D28, D29, D30, D31, D32, D33, D34, D35, D36, D37, D38, D39, D40, D41, D42, D43, D44, D45, D46, D47, D48, D49, D50, D51, D52, D53, D54, D55, D56, D57, D58, D59, D60, D61, D62, D63, D64, D65, D66, D67, D68, D69, D70, D71, D72, D73, D74, D75, D76, D77, D78, D79, D80, D81, D82, D83, D84, D85, D86, D87, D88, D89, D90, D91, D92, D93, D94, D95, D96, D97, D98, D99, D100, D101, D102, D103, D104, D105, D106, D107, D108, D109, D110, D111, D112, D113, D114, D115, D116, D117, D118, D119, D120, D121, D122, D123, D124, D125, D126, D127, D128, D129, D130, D131, D132, D133, D134, D135, D136, D137, D138, D139, D140, D141, D142, D143, D144, D145, D146, D147, D148, D149, D150, D151, D152, D153, D154, D155, D156, D157, D158, D159, D160, D161, D162, D163, D164, D165, D166, D167, D168, D169, D170, D171, D172, D173, D174, D175, D176, D177, D178, D179, D180: XL-1010RGBC-WS2812B; XINGLIGHT-XL-1010RGBC; LCSC Part C5349953

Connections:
+5VL: D4.2 (VCC), D5.2 (VCC), D6.2 (VCC), D7.2 (VCC), D8.2 (VCC), D9.2 (VCC), D10.2 (VCC), D11.2 (VCC), D12.2 (VCC), D13.2 (VCC), D14.2 (VCC), D15.2 (VCC), D16.2 (VCC), D17.2 (VCC), D18.2 (VCC), D19.2 (VCC), D20.2 (VCC), D21.2 (VCC), D22.2 (VCC), D23.2 (VCC), D24.2 (VCC), D25.2 (VCC), D26.2 (VCC), D27.2 (VCC), D28.2 (VCC), D29.2 (VCC), D30.2 (VCC), D31.2 (VCC), D32.2 (VCC), D33.2 (VCC), D34.2 (VCC), D35.2 (VCC), D36.2 (VCC), D37.2 (VCC), D38.2 (VCC), D39.2 (VCC), D40.2 (VCC), D41.2 (VCC), D42.2 (VCC), D43.2 (VCC), D44.2 (VCC), D45.2 (VCC), D46.2 (VCC), D47.2 (VCC), D48.2 (VCC), D49.2 (VCC), D50.2 (VCC), D51.2 (VCC), D52.2 (VCC), D53.2 (VCC), D54.2 (VCC), D55.2 (VCC), D56.2 (VCC), D57.2 (VCC), D58.2 (VCC), D59.2 (VCC), D60.2 (VCC), D61.2 (VCC), D62.2 (VCC), D63.2 (VCC), D64.2 (VCC), D65.2 (VCC), D66.2 (VCC), D67.2 (VCC), D68.2 (VCC), D69.2 (VCC), D70.2 (VCC), D71.2 (VCC), D72.2 (VCC), D73.2 (VCC), D74.2 (VCC), D75.2 (VCC), D76.2 (VCC), D77.2 (VCC), D78.2 (VCC), D79.2 (VCC), D80.2 (VCC), D81.2 (VCC), D82.2 (VCC), D83.2 (VCC), D84.2 (VCC), D85.2 (VCC), D86.2 (VCC), D87.2 (VCC), D88.2 (VCC), D89.2 (VCC), D90.2 (VCC), D91.2 (VCC), D92.2 (VCC), D93.2 (VCC), D94.2 (VCC), D95.2 (VCC), D96.2 (VCC), D97.2 (VCC), D98.2 (VCC), D99.2 (VCC), D100.2 (VCC), D101.2 (VCC), D102.2 (VCC), D103.2 (VCC), D104.2 (VCC), D105.2 (VCC), D106.2 (VCC), D107.2 (VCC), D108.2 (VCC), D109.2 (VCC), D110.2 (VCC), D111.2 (VCC), D112.2 (VCC), D113.2 (VCC), D114.2 (VCC), D115.2 (VCC), D116.2 (VCC), D117.2 (VCC), D118.2 (VCC), D119.2 (VCC), D120.2 (VCC), D121.2 (VCC), D122.2 (VCC), D123.2 (VCC), D124.2 (VCC), D125.2 (VCC), D126.2 (VCC), D127.2 (VCC), D128.2 (VCC), D129.2 (VCC), D130.2 (VCC), D131.2 (VCC), D132.2 (VCC), D133.2 (VCC), D134.2 (VCC), D135.2 (VCC), D136.2 (VCC), D137.2 (VCC), D138.2 (VCC), D139.2 (VCC), D140.2 (VCC), D141.2 (VCC), D142.2 (VCC), D143.2 (VCC), D144.2 (VCC), D145.2 (VCC), D146.2 (VCC), D147.2 (VCC), D148.2 (VCC), D149.2 (VCC), D150.2 (VCC), D151.2 (VCC), D152.2 (VCC), D153.2 (VCC), D154.2 (VCC), D155.2 (VCC), D156.2 (VCC), D157.2 (VCC), D158.2 (VCC), D159.2 (VCC), D160.2 (VCC), D161.2 (VCC), D162.2 (VCC), D163.2 (VCC), D164.2 (VCC), D165.2 (VCC), D166.2 (VCC), D167.2 (VCC), D168.2 (VCC), D169.2 (VCC), D170.2 (VCC), D171.2 (VCC), D172.2 (VCC), D173.2 (VCC), D174.2 (VCC), D175.2 (VCC), D176.2 (VCC), D177.2 (VCC), D178.2 (VCC), D179.2 (VCC), D180.2 (VCC); also elsewhere on the board
DATA_IN: D4.4 (DI); also elsewhere on the board
DATA_THRU1: D23.1 (DO), D24.4 (DI)
DATA_THRU2: D43.1 (DO), D44.4 (DI)
DATA_THRU3: D63.1 (DO), D64.4 (DI)
DATA_THRU4: D83.1 (DO), D84.4 (DI)
DATA_THRU5: D103.1 (DO), D104.4 (DI)
DATA_THRU6: D123.1 (DO), D124.4 (DI)
DATA_THRU7: D139.1 (DO), D140.4 (DI)
DATA_THRU8: D155.1 (DO), D156.4 (DI)
DATA_THRU9: D171.1 (DO), D172.4 (DI)
GND: D4.3 (GND), D5.3 (GND), D6.3 (GND), D7.3 (GND), D8.3 (GND), D9.3 (GND), D10.3 (GND), D11.3 (GND), D12.3 (GND), D13.3 (GND), D14.3 (GND), D15.3 (GND), D16.3 (GND), D17.3 (GND), D18.3 (GND), D19.3 (GND), D20.3 (GND), D21.3 (GND), D22.3 (GND), D23.3 (GND), D24.3 (GND), D25.3 (GND), D26.3 (GND), D27.3 (GND), D28.3 (GND), D29.3 (GND), D30.3 (GND), D31.3 (GND), D32.3 (GND), D33.3 (GND), D34.3 (GND), D35.3 (GND), D36.3 (GND), D37.3 (GND), D38.3 (GND), D39.3 (GND), D40.3 (GND), D41.3 (GND), D42.3 (GND), D43.3 (GND), D44.3 (GND), D45.3 (GND), D46.3 (GND), D47.3 (GND), D48.3 (GND), D49.3 (GND), D50.3 (GND), D51.3 (GND), D52.3 (GND), D53.3 (GND), D54.3 (GND), D55.3 (GND), D56.3 (GND), D57.3 (GND), D58.3 (GND), D59.3 (GND), D60.3 (GND), D61.3 (GND), D62.3 (GND), D63.3 (GND), D64.3 (GND), D65.3 (GND), D66.3 (GND), D67.3 (GND), D68.3 (GND), D69.3 (GND), D70.3 (GND), D71.3 (GND), D72.3 (GND), D73.3 (GND), D74.3 (GND), D75.3 (GND), D76.3 (GND), D77.3 (GND), D78.3 (GND), D79.3 (GND), D80.3 (GND), D81.3 (GND), D82.3 (GND), D83.3 (GND), D84.3 (GND), D85.3 (GND), D86.3 (GND), D87.3 (GND), D88.3 (GND), D89.3 (GND), D90.3 (GND), D91.3 (GND), D92.3 (GND), D93.3 (GND), D94.3 (GND), D95.3 (GND), D96.3 (GND), D97.3 (GND), D98.3 (GND), D99.3 (GND), D100.3 (GND), D101.3 (GND), D102.3 (GND), D103.3 (GND), D104.3 (GND), D105.3 (GND), D106.3 (GND), D107.3 (GND), D108.3 (GND), D109.3 (GND), D110.3 (GND), D111.3 (GND), D112.3 (GND), D113.3 (GND), D114.3 (GND), D115.3 (GND), D116.3 (GND), D117.3 (GND), D118.3 (GND), D119.3 (GND), D120.3 (GND), D121.3 (GND), D122.3 (GND), D123.3 (GND), D124.3 (GND), D125.3 (GND), D126.3 (GND), D127.3 (GND), D128.3 (GND), D129.3 (GND), D130.3 (GND), D131.3 (GND), D132.3 (GND), D133.3 (GND), D134.3 (GND), D135.3 (GND), D136.3 (GND), D137.3 (GND), D138.3 (GND), D139.3 (GND), D140.3 (GND), D141.3 (GND), D142.3 (GND), D143.3 (GND), D144.3 (GND), D145.3 (GND), D146.3 (GND), D147.3 (GND), D148.3 (GND), D149.3 (GND), D150.3 (GND), D151.3 (GND), D152.3 (GND), D153.3 (GND), D154.3 (GND), D155.3 (GND), D156.3 (GND), D157.3 (GND), D158.3 (GND), D159.3 (GND), D160.3 (GND), D161.3 (GND), D162.3 (GND), D163.3 (GND), D164.3 (GND), D165.3 (GND), D166.3 (GND), D167.3 (GND), D168.3 (GND), D169.3 (GND), D170.3 (GND), D171.3 (GND), D172.3 (GND), D173.3 (GND), D174.3 (GND), D175.3 (GND), D176.3 (GND), D177.3 (GND), D178.3 (GND), D179.3 (GND), D180.3 (GND); also elsewhere on the board
unnamed: D4.1 (DO), D5.4 (DI)
unnamed: D5.1 (DO), D6.4 (DI)
unnamed: D6.1 (DO), D7.4 (DI)
unnamed: D7.1 (DO), D8.4 (DI)
unnamed: D8.1 (DO), D9.4 (DI)
unnamed: D9.1 (DO), D10.4 (DI)
unnamed: D10.1 (DO), D11.4 (DI)
unnamed: D11.1 (DO), D12.4 (DI)
unnamed: D12.1 (DO), D13.4 (DI)
unnamed: D13.1 (DO), D14.4 (DI)
unnamed: D14.1 (DO), D15.4 (DI)
unnamed: D15.1 (DO), D16.4 (DI)
unnamed: D16.1 (DO), D17.4 (DI)
unnamed: D17.1 (DO), D18.4 (DI)
unnamed: D18.1 (DO), D19.4 (DI)
unnamed: D19.1 (DO), D20.4 (DI)
unnamed: D20.1 (DO), D21.4 (DI)
unnamed: D21.1 (DO), D22.4 (DI)
unnamed: D22.1 (DO), D23.4 (DI)
unnamed: D24.1 (DO), D25.4 (DI)
unnamed: D25.1 (DO), D26.4 (DI)
unnamed: D26.1 (DO), D27.4 (DI)
unnamed: D27.1 (DO), D28.4 (DI)
unnamed: D28.1 (DO), D29.4 (DI)
unnamed: D29.1 (DO), D30.4 (DI)
unnamed: D30.1 (DO), D31.4 (DI)
unnamed: D31.1 (DO), D32.4 (DI)
unnamed: D32.1 (DO), D33.4 (DI)
unnamed: D33.1 (DO), D34.4 (DI)
unnamed: D34.1 (DO), D35.4 (DI)
unnamed: D35.1 (DO), D36.4 (DI)
unnamed: D36.1 (DO), D37.4 (DI)
unnamed: D37.1 (DO), D38.4 (DI)
unnamed: D38.1 (DO), D39.4 (DI)
unnamed: D39.1 (DO), D40.4 (DI)
unnamed: D40.1 (DO), D41.4 (DI)
unnamed: D41.1 (DO), D42.4 (DI)
unnamed: D42.1 (DO), D43.4 (DI)
unnamed: D44.1 (DO), D45.4 (DI)
unnamed: D45.1 (DO), D46.4 (DI)
unnamed: D46.1 (DO), D47.4 (DI)
unnamed: D47.1 (DO), D48.4 (DI)
unnamed: D48.1 (DO), D49.4 (DI)
unnamed: D49.1 (DO), D50.4 (DI)
unnamed: D50.1 (DO), D51.4 (DI)
unnamed: D51.1 (DO), D52.4 (DI)
unnamed: D52.1 (DO), D53.4 (DI)
unnamed: D53.1 (DO), D54.4 (DI)
unnamed: D54.1 (DO), D55.4 (DI)
unnamed: D55.1 (DO), D56.4 (DI)
unnamed: D56.1 (DO), D57.4 (DI)
unnamed: D57.1 (DO), D58.4 (DI)
unnamed: D58.1 (DO), D59.4 (DI)
unnamed: D59.1 (DO), D60.4 (DI)
unnamed: D60.1 (DO), D61.4 (DI)
unnamed: D61.1 (DO), D62.4 (DI)
unnamed: D62.1 (DO), D63.4 (DI)
unnamed: D64.1 (DO), D65.4 (DI)
unnamed: D65.1 (DO), D66.4 (DI)
unnamed: D66.1 (DO), D67.4 (DI)
unnamed: D67.1 (DO), D68.4 (DI)
unnamed: D68.1 (DO), D69.4 (DI)
unnamed: D69.1 (DO), D70.4 (DI)
unnamed: D70.1 (DO), D71.4 (DI)
unnamed: D71.1 (DO), D72.4 (DI)
unnamed: D72.1 (DO), D73.4 (DI)
unnamed: D73.1 (DO), D74.4 (DI)
unnamed: D74.1 (DO), D75.4 (DI)
unnamed: D75.1 (DO), D76.4 (DI)
unnamed: D76.1 (DO), D77.4 (DI)
unnamed: D77.1 (DO), D78.4 (DI)
unnamed: D78.1 (DO), D79.4 (DI)
unnamed: D79.1 (DO), D80.4 (DI)
unnamed: D80.1 (DO), D81.4 (DI)
unnamed: D81.1 (DO), D82.4 (DI)
unnamed: D82.1 (DO), D83.4 (DI)
unnamed: D84.1 (DO), D85.4 (DI)
unnamed: D85.1 (DO), D86.4 (DI)
unnamed: D86.1 (DO), D87.4 (DI)
unnamed: D87.1 (DO), D88.4 (DI)
unnamed: D88.1 (DO), D89.4 (DI)
unnamed: D89.1 (DO), D90.4 (DI)
unnamed: D90.1 (DO), D91.4 (DI)
unnamed: D91.1 (DO), D92.4 (DI)
unnamed: D92.1 (DO), D93.4 (DI)
unnamed: D93.1 (DO), D94.4 (DI)
unnamed: D94.1 (DO), D95.4 (DI)
unnamed: D95.1 (DO), D96.4 (DI)
unnamed: D96.1 (DO), D97.4 (DI)
unnamed: D97.1 (DO), D98.4 (DI)
unnamed: D98.1 (DO), D99.4 (DI)
unnamed: D99.1 (DO), D100.4 (DI)
unnamed: D100.1 (DO), D101.4 (DI)
unnamed: D101.1 (DO), D102.4 (DI)
unnamed: D102.1 (DO), D103.4 (DI)
unnamed: D104.1 (DO), D105.4 (DI)
unnamed: D105.1 (DO), D106.4 (DI)
unnamed: D106.1 (DO), D107.4 (DI)
unnamed: D107.1 (DO), D108.4 (DI)
unnamed: D108.1 (DO), D109.4 (DI)
unnamed: D109.1 (DO), D110.4 (DI)
unnamed: D110.1 (DO), D111.4 (DI)
unnamed: D111.1 (DO), D112.4 (DI)
unnamed: D112.1 (DO), D113.4 (DI)
unnamed: D113.1 (DO), D114.4 (DI)
unnamed: D114.1 (DO), D115.4 (DI)
unnamed: D115.1 (DO), D116.4 (DI)
unnamed: D116.1 (DO), D117.4 (DI)
unnamed: D117.1 (DO), D118.4 (DI)
unnamed: D118.1 (DO), D119.4 (DI)
unnamed: D119.1 (DO), D120.4 (DI)
unnamed: D120.1 (DO), D121.4 (DI)
unnamed: D121.1 (DO), D122.4 (DI)
unnamed: D122.1 (DO), D123.4 (DI)
unnamed: D124.1 (DO), D125.4 (DI)
unnamed: D125.1 (DO), D126.4 (DI)
unnamed: D126.1 (DO), D127.4 (DI)
unnamed: D127.1 (DO), D128.4 (DI)
unnamed: D128.1 (DO), D129.4 (DI)
unnamed: D129.1 (DO), D130.4 (DI)
unnamed: D130.1 (DO), D131.4 (DI)
unnamed: D131.1 (DO), D132.4 (DI)
unnamed: D132.1 (DO), D133.4 (DI)
unnamed: D133.1 (DO), D134.4 (DI)
unnamed: D134.1 (DO), D135.4 (DI)
unnamed: D135.1 (DO), D136.4 (DI)
unnamed: D136.1 (DO), D137.4 (DI)
unnamed: D137.1 (DO), D138.4 (DI)
unnamed: D138.1 (DO), D139.4 (DI)
unnamed: D140.1 (DO), D141.4 (DI)
unnamed: D141.1 (DO), D142.4 (DI)
unnamed: D142.1 (DO), D143.4 (DI)
unnamed: D143.1 (DO), D144.4 (DI)
unnamed: D144.1 (DO), D145.4 (DI)
unnamed: D145.1 (DO), D146.4 (DI)
unnamed: D146.1 (DO), D147.4 (DI)
unnamed: D147.1 (DO), D148.4 (DI)
unnamed: D148.1 (DO), D149.4 (DI)
unnamed: D149.1 (DO), D150.4 (DI)
unnamed: D150.1 (DO), D151.4 (DI)
unnamed: D151.1 (DO), D152.4 (DI)
unnamed: D152.1 (DO), D153.4 (DI)
unnamed: D153.1 (DO), D154.4 (DI)
unnamed: D154.1 (DO), D155.4 (DI)
unnamed: D156.1 (DO), D157.4 (DI)
unnamed: D157.1 (DO), D158.4 (DI)
unnamed: D158.1 (DO), D159.4 (DI)
unnamed: D159.1 (DO), D160.4 (DI)
unnamed: D160.1 (DO), D161.4 (DI)
unnamed: D161.1 (DO), D162.4 (DI)
unnamed: D162.1 (DO), D163.4 (DI)
unnamed: D163.1 (DO), D164.4 (DI)
unnamed: D164.1 (DO), D165.4 (DI)
unnamed: D165.1 (DO), D166.4 (DI)
unnamed: D166.1 (DO), D167.4 (DI)
unnamed: D167.1 (DO), D168.4 (DI)
unnamed: D168.1 (DO), D169.4 (DI)
unnamed: D169.1 (DO), D170.4 (DI)
unnamed: D170.1 (DO), D171.4 (DI)
unnamed: D172.1 (DO), D173.4 (DI)
unnamed: D173.1 (DO), D174.4 (DI)
unnamed: D174.1 (DO), D175.4 (DI)
unnamed: D175.1 (DO), D176.4 (DI)
unnamed: D176.1 (DO), D177.4 (DI)
unnamed: D177.1 (DO), D178.4 (DI)
unnamed: D178.1 (DO), D179.4 (DI)
unnamed: D179.1 (DO), D180.4 (DI)

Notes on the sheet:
177 LEDs

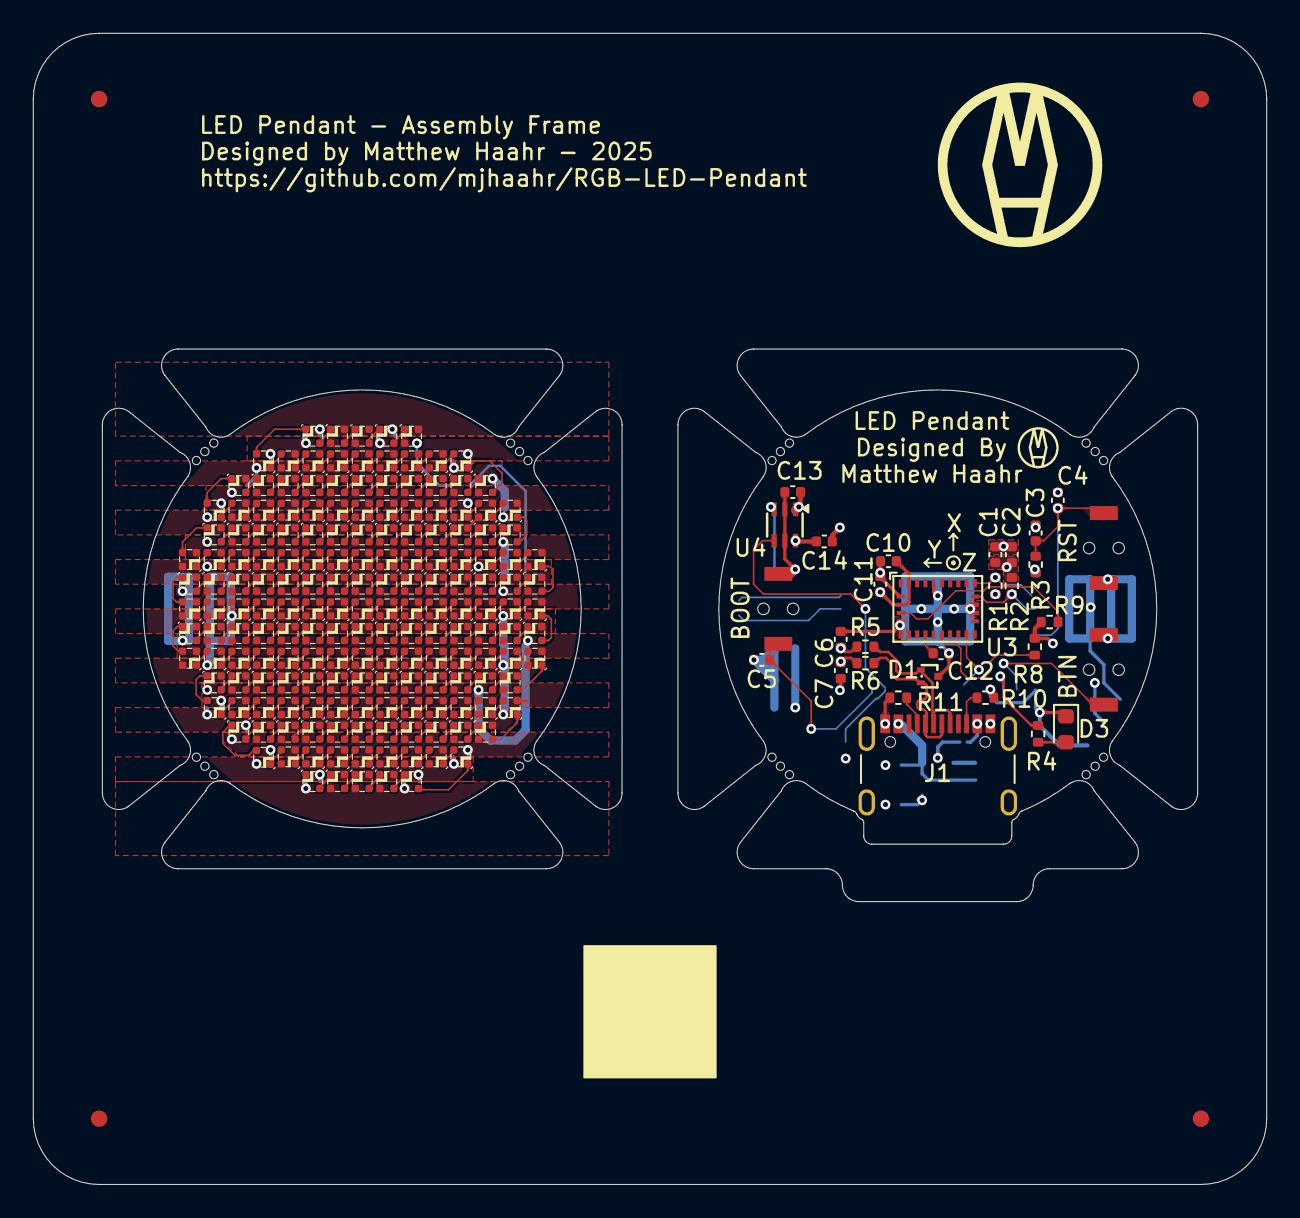
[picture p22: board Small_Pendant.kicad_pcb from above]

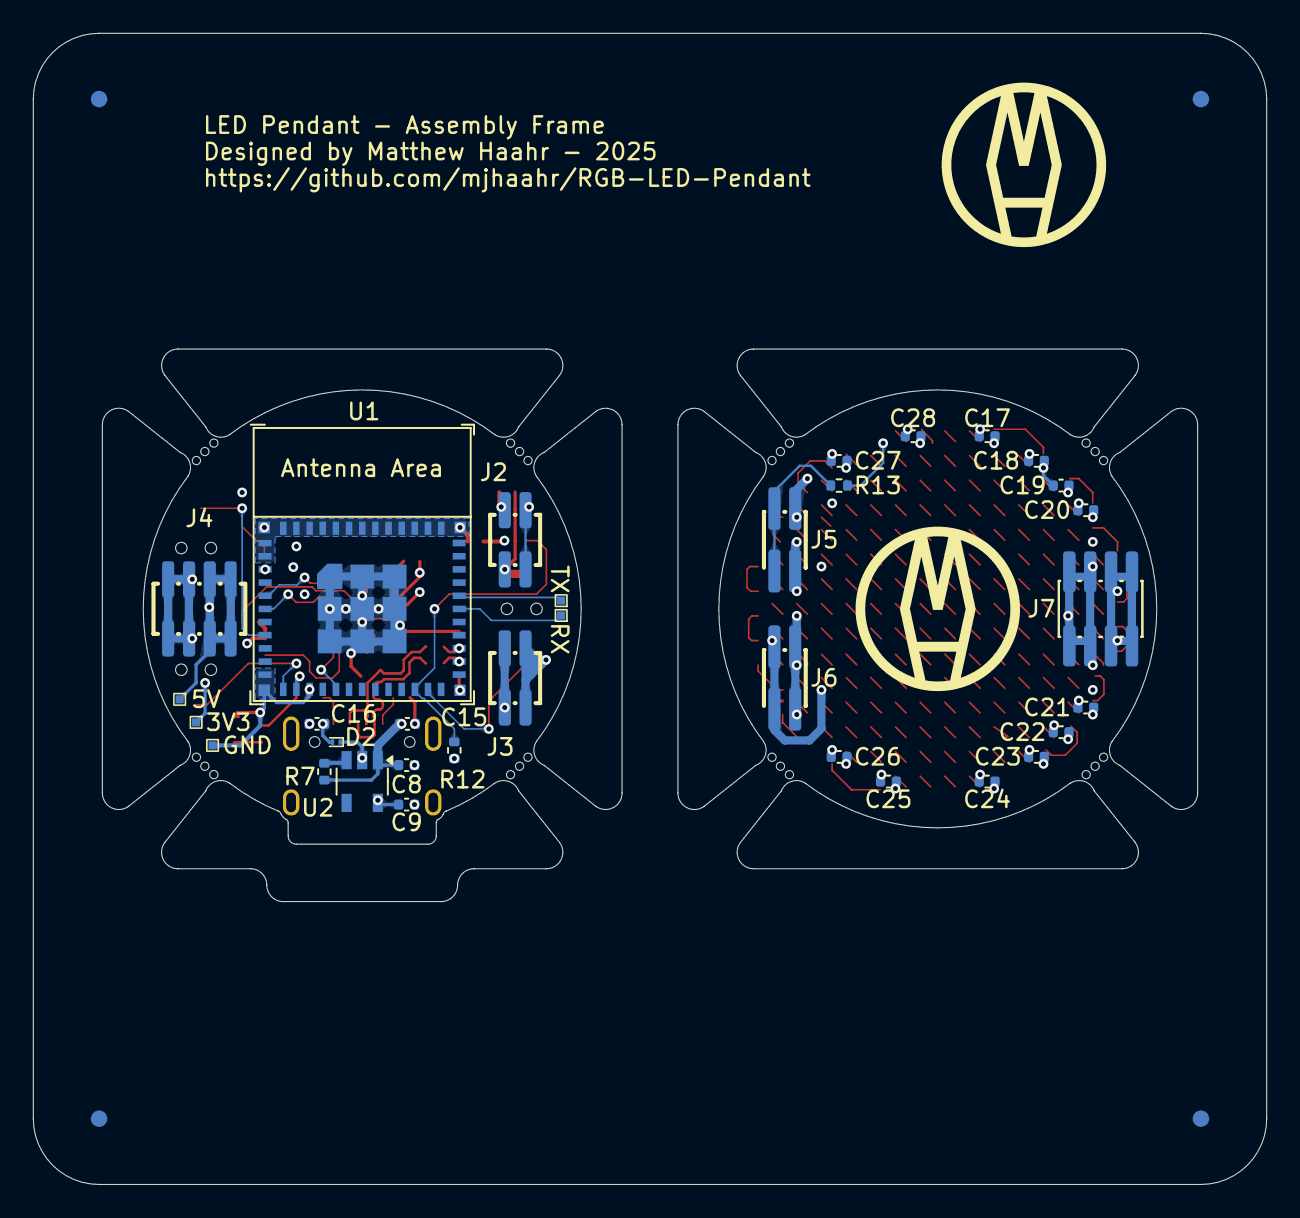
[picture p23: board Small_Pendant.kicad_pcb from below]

Board: 4 copper layers, 75.0 x 70.0 mm, 248 parts (33 on the bottom side), 205 nets.

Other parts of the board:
mouse-bite-2mm-slot, mouse-bite-2mm-slot#2, mouse-bite-2mm-slot#3, mouse-bite-2mm-slot#4, mouse-bite-2mm-slot#5, mouse-bite-2mm-slot#6, mouse-bite-2mm-slot#7, mouse-bite-2mm-slot#8: VAL**; mouse-bite-2mm-slot_round

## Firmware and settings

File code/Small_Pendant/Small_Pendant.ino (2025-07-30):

/**
 * @file        Small_Pendant.ino
 * @module      The Main (Small_Pendant) Module
 *
 * @brief       Contains the Main code for the Small Pendant Project (Init and Task Dispatching)
 *
 * @author      Matthew Haahr (mjhaahr)
 */
#include "Config.hpp"
#include "Util.hpp"
#include "Buttons.hpp"
#include "Display.hpp"

hw_timer_t *taskTimer = NULL;
volatile SemaphoreHandle_t taskSemaphore;

void ARDUINO_ISR_ATTR taskStart() {
	xSemaphoreGiveFromISR(taskSemaphore, NULL);
}

void setup() {
    BTN_Init();
    DISP_Init();

    Wire.setPins(SDA_IMU, SCL_IMU);

    // TODO: Setup IMU and add the calibration getter here

    pinMode(LED_BUILTIN, OUTPUT);
    digitalWrite(LED_BUILTIN, LOW);

    DebugBegin(57600);
    DebugPrintln("Start");

    // Create semaphore to flag when timer has fired
    taskSemaphore = xSemaphoreCreateBinary();

    // Set timer frequency to 1Mhz
    taskTimer = timerBegin(1000000);

    // Attach taskStart ISR to task timer.
    timerAttachInterrupt(taskTimer, &taskStart);

    // Set task timer alarm to call taskStart ISR with the SysTick Period
    // Repeat the alarm (3rd param = true) with unlimited count (4th param = 0).
    timerAlarm(taskTimer, SYSTICK_PERIOD_US, true, 0);
}

void loop() {
    // Start UI Update Tracking at 0
    static uint8_t uiUpdateTicks = 0;
    
    // If Task Timer has fired
    if (xSemaphoreTake(taskSemaphore, 0) == pdTRUE) {
        // Increment display update check (runs every UI_UPDATE_INT ticks)
        if (++uiUpdateTicks >= UI_UPDATE_INT) {
            uiUpdateTicks = 0;
            // Check buttons
            BTN_Task();
            // Update display
            DISP_Task();
        } else {
          // Redraw the current display otherwise to update temporal dithering
          // DISP_Redraw();
        }
    }
}

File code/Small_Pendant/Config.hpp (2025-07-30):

/**
 * @file        Config.hpp
 * @module      The Configuration Module (CFG)
 *
 * @brief       Contains General Configuration Code for the Small Pendant Project
 *
 * @author      Matthew Haahr (mjhaahr)
 */
#ifndef __CONFIG_H__
#define __CONFIG_H__

#include <Arduino.h>
#include <FastLED.h>
#include <Wire.h>

#undef DEBUG

// System Update
#define SYSTICK_PERIOD_MS           8u
#define SYSTICK_PERIOD_US           (SYSTICK_PERIOD_MS * 1000u)
#define SYSTICK_FREQ                (1000u / SYSTICK_PERIOD_MS)

// Update UI (Buttons and Display) after a certain number of Sys Ticks
#define UI_UPDATE_PERIOD_MS         8u
#define UI_UPDATE_FREQ              (1000u / UI_UPDATE_PERIOD_MS)
#define UI_UPDATE_INT               (UI_UPDATE_PERIOD_MS / SYSTICK_PERIOD_MS)

// Pin Defines
#define LED_PIN                     8u
#define BOOT_COLOR_BUTTON_PIN       0u
#define USER_PATTERN_BUTTON_PIN     9u

#define SDA_IMU                     2u
#define SCL_IMU                     3u

#undef BUILTIN_LED
#undef LED_BUILTIN
#define BUILTIN_LED                 1u
#define LED_BUILTIN                 BUILTIN_LED

#define GPIO_BUTTON_PRESSED         LOW
#define GPIO_BUTTON_UNPRESSED       HIGH

// LED Setup
#define NUM_LEDS                    177u
#define MAX_BRIGHTNESS              13u

#ifdef DEBUG
    #define DebugBegin(...) Serial.begin(__VA_ARGS__);
    #define DebugPrint(...) Serial.print(__VA_ARGS__);
    #define DebugPrintln(...) Serial.println(__VA_ARGS__);
    #define DebugWrite(...) Serial.write(__VA_ARGS__);
#else
    #define DebugBegin(...)
    #define DebugPrint(...)
    #define DebugPrintln(...)
    #define DebugWrite(...)
#endif

#endif /* __CONFIG_H__ */

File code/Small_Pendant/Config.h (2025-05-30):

/**
 * @file        Config.h
 * @module      The Configuration Module (CONFIG)
 *
 * @brief       Contains General Configuration Code for the Small Pendant Project
 *
 * @author      Matthew Haahr (mjhaahr)
 */
#ifndef __CONFIG_H__
#define __CONFIG_H__

#include <Arduino.h>
#include <FastLED.h>

// System Update
#define UPDATE_RATE                 100u
#define UPDATE_PERIOD               (1000u / UPDATE_RATE)

// Pin Defines
#define LED_PIN                     8u
#define BOOT_COLOR_BUTTON_PIN       9u
#define USER_PATTERN_BUTTON_PIN     0u

// LED Setup
#define NUM_LEDS                    177u
#define MAX_BRIGHTNESS              15u

#endif /* __CONFIG_H__ */

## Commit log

2025-01-26 [HW] Laid out 177 LEDs and 20 decoupling caps (may need more) TODO: Pick MCU and add support components
    [Capacitors.kicad_sch, LEDs.kicad_sch, Small_Pendant.kicad_pcb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]
2025-01-26 [HW] Add Round tracks
    [Small_Pendant.kicad_pcb]
2025-01-26 [HW] Add HW TODOs
    [Small_Pendant.kicad_sch]
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2025-01-27 [HW] Add FTDI and level translator Needs MCU, VREGs, and Charge Controller May make overall board larger to allow for that (and add locs for USB mechanical pins
    [MCU.kicad_sch, Small_Pendant.kicad_pcb, Small_Pendant.kicad_sch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]
2025-01-29 [HW] Switch to Via In Pad for many pads
    [Small_Pendant.kicad_pcb]
2025-01-29 [HW] Cont on new layout
    [Small_Pendant.kicad_pcb]
2025-01-29 [HW] Place Caps and finish simple reroute, need to fiugre out usb port without drills
    [MCU.kicad_sch, Small_Pendant.kicad_pcb]
2025-01-29 [HW] Playing around with zones
    [Small_Pendant.kicad_pcb]
2025-02-01 [HW] Make 'lollipop' shaped for USB connector
    [Small_Pendant.kicad_pcb, USB+Power.kicad_sch]
2025-02-02 [HW] Re-arrange and clean up, all current components placed
    [Small_Pendant.kicad_pcb]
2025-02-02 [HW] Update TODOs and combine USB Power Rails
    [MCU.kicad_sch, Small_Pendant.kicad_pcb, Small_Pendant.kicad_sch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]
2025-03-03 [HW] Remove Blind Vias, add 5k1 CC resistors for 5V3A USB-C TODO: 3V3 Regulator (May switch FTDI to that) TODO: MCU (OSC?)
    [MCU.kicad_sch, Small_Pendant.kicad_pcb]
2025-03-03 [HW] Todos
    Maybe re-think board devision:
    Sandwich boards with interconnect
    One board does just the LEDs (in a circule), connected to the interconnect
    While the other has the MCU, Handles Power, etc..., should make programming easier
    Would simplify the layout of the second board
    I like this better than the pain of having to route around the LEDs
    [Small_Pendant.kicad_sch]
2025-03-20 [HW] Update TODOs with chosen parts
    [Small_Pendant.kicad_sch]
2025-03-26 [HW] Split Boards, need to move Caps for LEDs and add all the assorcted stuff for the ESP32
    [MCU.kicad_sch, Small_Pendant.kicad_pcb, Small_Pendant.kicad_sch]
2025-03-28 [HW] Figure out MCU board shape and add power and ground planes
    [MCU.kicad_sch, Small_Pendant.kicad_pcb]
2025-03-30 [HW] Added IMU and corrected UART Bridge, all chip support components added, still need reset and boot connections though
    [BNO055.step, LED-Support.kicad_sch, MCU.kicad_sch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]
2025-03-30 [HW] Move Support Components in
    [MCU.kicad_sch, Small_Pendant.kicad_pcb]
2025-03-30 [HW] Add Buttons and Replace Transistors Picked a Connector, need to create symbol and footprint Need VREG, then that's all components Still lots of DRC issues
    [LED-Support.kicad_sch, LEDs.kicad_sch, MCU.kicad_sch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]
2025-03-30 [HW] Fix USB Routing
    [Small_Pendant.kicad_pcb]
2025-03-30 [HW] Update Caps on LED Board, clear lots of DRC violations
    [LED-Support.kicad_sch, Small_Pendant.kicad_pcb]
2025-03-30 [HW] Better Routing for some signals Swap Level Shifter
    [Small_Pendant.kicad_pcb]
2025-03-31 [HW] Added ESD Diode, Added VREG TODO: Connectors TODO?: Status LEDs (PWR vs Boot) (LED built in is a good idea to have, could blink every second to show alive-ness)
    [LEDs.kicad_sch, MCU.kicad_sch, Small_Pendant.kicad_pcb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]
2025-03-31 [HW] Enlarge Board Area, need to re-route
    [Small_Pendant.kicad_pcb]
2025-03-31 [HW] More Rearrangement TODO: Renumber all components, so they're not dumb Also pick some goddamn LEDs so I can use D* and add that to renumbering
    [MCU.kicad_sch, Small_Pendant.kicad_pcb]
2025-03-31 [HW] Re-annotate components, which absolutely wrecked everything, need to re-do the layout again
    [LED-Support.kicad_sch, LEDs.kicad_sch, MCU.kicad_sch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]
2025-03-31 [HW] Finished re-laying out the front
    [LED-Support.kicad_sch, MCU.kicad_sch, Small_Pendant.kicad_pcb]
2025-03-31 [HW] Add Caps to top board TODO: Interboard connectors TODO: Status LED + Resistor (place LED on Front Cu) TODO: Test Points for 5V, 3V3, GND
    [Small_Pendant.kicad_pcb]
2025-04-01 [HW] Added Connectors, P1.27mm double wide headers
    [LED-Support.kicad_sch, LEDs.kicad_sch, MCU.kicad_sch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]
2025-04-01 Removed USB to UART IC, instead using the built in USB on the ESP32-C3 (JTAG/USB-CDC combo in hardware) Added another connector, so total of 5 of each power line (5A without melting?) Renumbered and 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
    [LED-Support.kicad_sch, MCU.kicad_sch, Small_Pendant.kicad_pcb]
2025-04-01 [HW] Add LED (green) That's all the parts, now need to spec caps and resistors
    [LED-Support.kicad_sch, LEDs.kicad_sch, MCU.kicad_sch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]
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2025-04-02 [HW] Add Test Points [SW] Update the board configs correctly
    [MCU.kicad_sch, Small_Pendant.kicad_pcb]
2025-04-02 [HW] switched J4/7 to 2x4 connectors for more current capacity
    [LED-Support.kicad_sch, LEDs.kicad_sch, MCU.kicad_sch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]
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2025-04-02 [Docs] Lots added to the Readme, BOM, schematics,...
    [LED-Support.kicad_sch, MCU.kicad_sch, Small_Pendant.kicad_pcb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]
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2025-04-07 [HW] Add Series Resistor and power ESD diode
    [LED-Support.kicad_sch, LEDs.kicad_sch, MCU.kicad_sch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]
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2025-04-10 [HW] Go through every part an ensure it matches the JLCPCB variant
    [LED-Support.kicad_sch, MCU.kicad_sch, Small_Pendant.kicad_pcb]
2025-04-10 [Hw] Fix component issues with JLCPCB Placement Still Need Fixes: U1: ESP32 (it's offset) U2: 3V3 Reg (Rotated) D1: USB Data ESD (Rotated, check that Footprint matches) D2: USB PWR ESD (Rotated?) J1: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
    [MCU.kicad_sch, Small_Pendant-bom.csv, Small_Pendant.kicad_pcb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]
2025-04-10 Fixed a few placement correlation issues
    Still TODO:
    J1: USB (Footprint generating DRC Errors)
    J7: Interboard (Missing LCSC Part, wait for it to be added)
    [Small_Pendant.kicad_pcb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]
2025-04-10 [HW] Fix 'all' component issue, still unsure of the male 8pin jumper
    [LED-Support.kicad_sch, MCU.kicad_sch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]
2025-04-11 [HW] Add Teardrops TODO: Wait for EasyEDA/LCSC/JLCPCB to create the footprint/part for J7
    Also started hand panelization, we'll see if that works with the two different designs, likely will stagger them top and bottom
    [Small_Pendant.kicad_pcb]
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2025-04-11 [HW] Finalize production outputs for fab Not 100% sure everything is fine, but it should be
    [LED-Support.kicad_sch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]
2025-04-11 [HW] Fix production file issues
    [Small_Pendant-B_Cu.gbr, Small_Pendant-B_Mask.gbr, Small_Pendant-B_Paste.gbr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]
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2025-04-29 [Case] Create STEP files of finished boards for Case design"
    [led_board.step]
2025-05-16 [HW] Add Missing Bootstrap Pin
    [LED-Support.kicad_sch, MCU.kicad_sch, Small_Pendant.kicad_pcb]
2025-05-16 [HW] Update Fab and Docs for GPIO8 Strapping Pull-Up
    [Small_Pendant-B_Cu.gbr, Small_Pendant-B_Mask.gbr, Small_Pendant-B_Paste.gbr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]
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2025-05-19 [SW] Fix re-wrap bug and precalc color scale
    [Small_Pendant.ino]
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2025-07-14 [Case] Printed and Assembled First Case TODO: Images and Alternate with No Loop
    [LED Side.stl, MCU Side.stl, Small Pendant Case.3mf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]
2025-07-19 Solve dither caused issue
    [Button.cpp, Config.hpp, Small_Pendant.ino]
2025-07-20 [SW] Fixes post Day1 of OpenSauce and add Cylon
    [Config.hpp]
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
